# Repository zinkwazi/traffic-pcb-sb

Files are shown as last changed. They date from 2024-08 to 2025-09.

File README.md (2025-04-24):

# Traffic PCB SB
This project is a decorative and interactive display piece that shows the current traffic in the greater Los Angeles area. It sources data from [TomTom's](https://www.tomtom.com) traffic APIs, which supplies real-time traffic data. Each LED corresponds to an OpenLR road segment and data is queried from TomTom every hour. The way data is retrieved is likely to improve in the future. The device uses an ESP32S3 to control LEDs and refreshes the display every 5 minutes, during which LED colors will update if a change in road speed occurs. Please
reference the User Guide below to understand how to configure the device and interpret indicator lights. Enjoy!

# Features
1. Real-time traffic updates of 403 LEDs and nearly 800 data points.
2. Over the air (OTA) updates with daily firmware availability checks.
3. UART configuration menu (115200 baud) stored in non-volatile memory (remembered across reboots).
4. Offline operation with the most recently collected data displayed.

# User Manual
### Quickstart Guide
In order to start using your board, you must first configure it to connect to a wifi network. This is achieved through a 115200 baud UART menu exposed via the USB-C connector. Once connecting your USB-C cable to your computer, a COM device should be discoverable and communication via UART can be opened in the Arduino IDE or another program. The menu should open automatically and prompt you for wifi credentials (note that backspace is not accepted). If it does not open automatically, the menu is accessable by holding the "Toggle" button (until the menu is opened) and pressing the "Restart" button. Once configuration is complete, the device will reset. Then, the device will spend some time loading and collecting road segment data. It will refresh the LEDs once complete, after which pressing the "Toggle" button will change the direction of traffic flow being displayed from the Southeast direction to the Northwest direction. If a firmware update is available, with newer features and bug fixes, the OTA indicator light will strobe green. Pressing the "Update" button will download the update and the light will turn solid green if successful, otherwise it will turn solid
red if unsucessful.

### Board Anatomy


In the lower left corner of the board is the control panel and above that is the direction panel. The three chips located throughout the board are LED matrix drivers which receive commands via I2C from the ESP32S3. The control panel contains the USB-C connector, which communicates with the ESP32S3 via UART at 115200 baud; the 'Update' button, which initiates an over the air update; the 'Restart' button, which reboots the ESP32S3; and status LED indicators. The direction panel contains the 'Toggle' button and LED indicators that show the current traffic direction being displayed — either Southeast or Northwest.

### Understanding Road LEDs
Each road LED on the board corresponds to two OpenLR road segments: one northbound, and one southbound. Some road segments cross the coordinates of multiple LEDs, which are all refreshed with a single API call. Version 2 of the device features configurable LED colors, where the legend of colors is located just below the direction panel. Road segments are classified as fast (always blue or green in version 1) when the segment speed is at least 80% of its normal speed, medium (orange or yellow in version 1) when between 50% and 80%, and slow (red in version 1) when below 50% of its normal speed. Finally, LEDs at intersections of freeways always prioritize showing the segment speed of the freeway oriented most vertically.

### LED Indicator States
The board can be in one of the following states, discussed further below:
- Initialization: The traffic direction LEDs are strobing in a loading circle pattern. The device has just been powered on or rebooted, and is initializing the device. This may take longer than expected if there is trouble connecting to the wifi network.
- Configuration change is requested: The error LED is on and the traffic direction LEDs are flashing.
- An OTA update is available: The OTA LED is strobing green. Pressing the "Update" button will update the firmware to the latest version if connected to wifi.
- An OTA update is in progress: The OTA LED is solid white. After updating, the LED will momentarily turn either green or red to indicate update success or failure.
- A server error has occurred: The error LED is flashing. This indicates that data retrieval has failed, and the device may not be displaying live data anymore.
- A fatal error has occurred: The error LED momentarily turns red, and the device resets. This can happen for a variety of reasons. If this occurs often, an issue can be created in this repository and you will be helped in a timely manner.

### Configuration Changes
The user can change which wifi network the device attempts to connect to through a 115200 baud UART menu exposed via the USB-C connector. This menu is accessed by holding the "Toggle" button (until the menu is opened) and pressing the "Restart" button. The menu is active when the error LED is on and the traffic LEDs are flashing. If you are having trouble accessing the menu, please be sure to hold the "Toggle" button until these indicators are active. The device will request various configuration settings and, unfortunately, you will not be able to see what you type until you press ENTER. Once configuration is complete, the device will reset. A known bug is that the device cannot connect to some networks with particular SSIDs (names); For example, it will not connect to a network named "Jaden's IPhone", however it will connect to "JadenIPhone".

### Versioning
In the 'releases' tab of the repository you can find various firmware binaries that can manually be flashed onto the device in case something goes wrong with OTA updates, or you would prefer a previous device version. Please note that patch versions, v0.0.X, are mandatory and the device will automatically update to the latest known patch version if it is still available on the server. For example, if the latest available version on the server is v0.7.3 and you manually flash v0.7.1 onto the device, the device will automatically update to v0.7.3. However, if you flash v0.6.0, then the device will not update to any v0.6.X or v0.7.X manually.

Hardware versions are denoted: V[hardware_version]_[hardware_revision]. The hardware version and revision of your board is indicated just above the control panel.
Firmware versions are denoted: v[major_version].[minor_version].[patch_version]. Patch updates are mandatory, but major/minor version updates will be indicated as available.

# Contribution Guide

### Flashing Firmware Guide (preliminary)
1. download vscode
2. on the lefthand side, open extensions tab (four boxes button)
3. search for ESP-IDF from espressif and download
4. Open setup wizard (alternatively cmd+shift+p, then ">ESP-IDF: Setup extension")
5. clone repo
6. open esp-firmware folder and use setup wizard again if necessary, use v5.4.x or v5.3.x.
7. wait for download to complete, follow terminal instructions if errors. This is very likely to be a problematic step,
and unfortunately will not allow the next steps to work if it fails. If
there are issues, follow [ESP-IDF Get Started Guide](https://docs.espressif.com/projects/esp-idf/en/stable/esp32/get-started/index.html) instructions. Again,
this is highly likely to be very problematic and will likely require a lot of troubleshooting. Navigating to user/esp/install.sh and user/esp/export.sh and running ./install.sh might fix it. Also, running
"sudo -H ./install.sh" after restarting the terminal on MAC may be helpful. I think that the v5.3.x script requires python < v3.8, however the tool downloads v3.9 automatically? I recommend trying v5.4.x
if this happens, but really this is an issue to ask esp-idf maintainers about how to solve.
9. if everthing is done, go to commands with (cmd+shift+p).
10. Execute ">ESP-IDF: Select Project Configuration" and choose developV2_0 if flashing for hardware version 2.
11. On the bottom blue bar, if "esp32" is shown as the device target, change it to "esp32s3" for hardware version 2. This step is important, as it creates the build directory and sdkconfig file.
12. click on the wrench icon in the bottom blue bar to build the project under the chosen configuration. Alternatively,
use command "ESP-IDF: Build your project". Wait for the build to complete. If there are errors, contact Jaden or fix them.
13. Plug in board to usb port and hold "Update" through a click of "Restart". Continue holding update until a new COM port
is discovered in the device manager. Holding "Update" through a restart boots the ESP32 into USB flashing mode.
11. Click the plug symbol on the blue bar to select the correct COM port, or execute ">ESP-IDF: Select Port" and 
select the correct port for the connected board.
12. Click the star symbol, or execute ">ESP-IDF: Select flash method" and choose UART.
13. Click either the lightning bolt symbol or flame symbol to either flash the device or flash the device and then monitor
the device logs, respectively. Alternatively, use the corresponding commands: "ESP-IDF: Flash your project" and
"ESP-IDF: Build, Flash, and Monitor".
14. Monitor the output, which should display the firmware and hardware version in red at some point. If the hardware version
is not V2_0, then you have flashed V1_0 firmware to the device and need to select the develop_V2_0 configuration with
"ESP-IDF: Select project configuration". If the firmware version is not v0.5.x, then an issue exists, which is likely that
the default build configurations have not made it into the build. Contact Jaden for help.
15. If the device is asking for wifi settings, type them in carefully (you currently cannot use backspace), however don't
worry if the credentials are incorrect as you can change them later. The device will reset.
16. Give the device some time to perform initialization and grab initial data. Watch the logs for any errors, or watch
the error LED, which will blink or be solid red if something went wrong, such as the wifi credentials being incorrect.
17. To change the wifi credentials again, hold "Toggle" through a reset and be very patient because, for some yet unknown
reason, the device has a crazy boot time. You will boot into the wifi configuration menu where you can update the wifi
credentials.
18. Congrats! Things should be working. If not, contact Jaden.

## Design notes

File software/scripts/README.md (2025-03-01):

## generate_led_coordinates.py

**Assists in the generation of C arrays which describe the x, y PCB coordinates
of each LED on a version of the board.**

**Input:** A CSV file containing the CPL data of every designator on the board. This
should include at least the following headers: "Designator", "Mid X", "Mid Y".
The script will ignore all designators not of the form "LEDx", where x is a 
unique integer.

**Example Input:**

```
Designator,Val,Package,Mid X,Mid Y,Rotation,Layer
F1,3A,Fuse_1206_3216Metric,9.271,-182.499,-90,top
F2,3A,Fuse_1206_3216Metric,58,-163.5,180,top
J2,USB C,USB_C_Receptacle_HRO_TYPE-C-31-M-12,4,-177.8,-90,top
LED1,LED_ARGB,LED_RGB_0606,5.0292,-27.0256,0,top
LED2,LED_ARGB,LED_RGB_0606,39.7256,-29.972,0,top
LED6,LED_ARGB,LED_RGB_0606,197.9168,-86.5124,0,top
LED5,LED_ARGB,LED_RGB_0606,201.1172,-88.8492,0,top
LED4,LED_ARGB,LED_RGB_0606,204.8256,-90.4748,0,top
```

**Output:** A text file containing the C array describing the PCB's LED x, y coordinates,
where each index 'i' in the array corresponds to LED 'i'.. A comment is created 
alongside any indices that did not have a corresponding entry in the input file. 
Fractional portions of the input coordinates are rounded to the nearest integer.

**Example Output:**

```
/* A mapping from LED number to corresponding
x, y PCB coordinates. */
static const LEDCoord LEDNumToCoord[] = {
    {0, 0}, // there is no LED with number 0
    {5, -27}, // 1
    {40, -30}, // 2
    {0, 0}, // there is no LED with number 3
    {205, -90}, // 4
    {201, -89}, // 5
};
```

**Example Explanation:** Input designators F1, F2, and J2 are ignored and do
not affect the output. Similarly, the order of designators "LEDx" is ignored.
Index 2 of the output contains the "Mid X" and "Mid Y" respectively, rounded
to the nearest integer. There is no "LED3" designator, so index 3 of the output
is set to {0, 0} and a comment is created documenting absence.

**Usage:** 
```
python3 generate_led_coordinates.py inputCPL.csv [output.txt]
```

If no output file is provided, the script will present the generated struct
to stdout.

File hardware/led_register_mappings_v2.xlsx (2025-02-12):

MATRIX4 |  | 1 | 2 | 3 | 4 | 5 | 6 | 7 | 8 | 9 | MATRIX4 |  | 1 | 2 | 3 | 4 | 5 | 6 | 7 | 8 | 9
 |  | COL8 | COL7 | COL6 | COL5 | COL4 | COL0 | COL1 | COL2 | COL3 |  |  | COL0 | COL1 | COL2 | COL3 | COL4 | COL5 | COL6 | COL7 | COL8
39 | ROW1 | 0x62 | 0x6B | 0x74 | 0x7D | 0x86 | 0x8F | 0x98 | 0xA1 | 0xAA | 39 | ROW1 | 0x8F | 0x98 | 0xA1 | 0xAA | 0x86 | 0x7D | 0x74 | 0x6B | 0x62
38 | ROW2 | 0x61 | 0x6A | 0x73 | 0x7C | 0x85 | 0x8E | 0x97 | 0xA0 | 0xA9 | 38 | ROW2 | 0x8E | 0x97 | 0xA0 | 0xA9 | 0x85 | 0x7C | 0x73 | 0x6A | 0x61
37 | ROW0 | 0x60 | 0x69 | 0x72 | 0x7B | 0x84 | 0x8D | 0x96 | 0x9F | 0xA8 | 37 | ROW0 | 0x8D | 0x96 | 0x9F | 0xA8 | 0x84 | 0x7B | 0x72 | 0x69 | 0x60
36 | ROW4 | 0x5F | 0x68 | 0x71 | 0x7A | 0x83 | 0x8C | 0x95 | 0x9E | 0xA7 | 36 | ROW4 | 0x8C | 0x95 | 0x9E | 0xA7 | 0x83 | 0x7A | 0x71 | 0x68 | 0x5F
35 | ROW5 | 0x5E | 0x67 | 0x70 | 0x79 | 0x82 | 0x8B | 0x94 | 0x9D | 0xA6 | 35 | ROW5 | 0x8B | 0x94 | 0x9D | 0xA6 | 0x82 | 0x79 | 0x70 | 0x67 | 0x5E
34 | ROW3 | 0x5D | 0x66 | 0x6F | 0x78 | 0x81 | 0x8A | 0x93 | 0x9C | 0xA5 | 34 | ROW3 | 0x8A | 0x93 | 0x9C | 0xA5 | 0x81 | 0x78 | 0x6F | 0x66 | 0x5D
33 | ROW8 | 0x5C | 0x65 | 0x6E | 0x77 | 0x80 | 0x89 | 0x92 | 0x9B | 0xA4 | 33 | ROW8 | 0x89 | 0x92 | 0x9B | 0xA4 | 0x80 | 0x77 | 0x6E | 0x65 | 0x5C
32 | ROW7 | 0x5B | 0x64 | 0x6D | 0x76 | 0x7F | 0x88 | 0x91 | 0x9A | 0xA3 | 32 | ROW7 | 0x88 | 0x91 | 0x9A | 0xA3 | 0x7F | 0x76 | 0x6D | 0x64 | 0x5B
31 | ROW6 | 0x5A | 0x63 | 0x6C | 0x75 | 0x7E | 0x87 | 0x90 | 0x99 | 0xA2 | 31 | ROW6 | 0x87 | 0x90 | 0x99 | 0xA2 | 0x7E | 0x75 | 0x6C | 0x63 | 0x5A
30 | ROW11 | 0x1D | 0x3B | 0x59 | 0x77 | 0x95 | 0xB3 | 0x1D | 0x3B | 0x59 | 30 | ROW11 | 0xB3 | 0x1D | 0x3B | 0x59 | 0x95 | 0x77 | 0x59 | 0x3B | 0x1D
29 | ROW10 | 0x1C | 0x3A | 0x58 | 0x76 | 0x94 | 0xB2 | 0x1C | 0x3A | 0x58 | 29 | ROW10 | 0xB2 | 0x1C | 0x3A | 0x58 | 0x94 | 0x76 | 0x58 | 0x3A | 0x1C
28 | ROW9 | 0x1B | 0x39 | 0x57 | 0x75 | 0x93 | 0xB1 | 0x1B | 0x39 | 0x57 | 28 | ROW9 | 0xB1 | 0x1B | 0x39 | 0x57 | 0x93 | 0x75 | 0x57 | 0x39 | 0x1B
27 | ROW14 | 0x1A | 0x38 | 0x56 | 0x74 | 0x92 | 0xB0 | 0x1A | 0x38 | 0x56 | 27 | ROW14 | 0xB0 | 0x1A | 0x38 | 0x56 | 0x92 | 0x74 | 0x56 | 0x38 | 0x1A
26 | ROW13 | 0x19 | 0x37 | 0x55 | 0x73 | 0x91 | 0xAF | 0x19 | 0x37 | 0x55 | 26 | ROW13 | 0xAF | 0x19 | 0x37 | 0x55 | 0x91 | 0x73 | 0x55 | 0x37 | 0x19
25 | ROW12 | 0x18 | 0x36 | 0x54 | 0x72 | 0x90 | 0xAE | 0x18 | 0x36 | 0x54 | 25 | ROW12 | 0xAE | 0x18 | 0x36 | 0x54 | 0x90 | 0x72 | 0x54 | 0x36 | 0x18
24 | ROW17 | 0x17 | 0x35 | 0x53 | 0x71 | 0x8F | 0xAD | 0x17 | 0x35 | 0x53 | 24 | ROW17 | 0xAD | 0x17 | 0x35 | 0x53 | 0x8F | 0x71 | 0x53 | 0x35 | 0x17
23 | ROW16 | 0x16 | 0x34 | 0x52 | 0x70 | 0x8E | 0xAC | 0x16 | 0x34 | 0x52 | 23 | ROW16 | 0xAC | 0x16 | 0x34 | 0x52 | 0x8E | 0x70 | 0x52 | 0x34 | 0x16
22 | ROW15 | 0x15 | 0x33 | 0x51 | 0x6F | 0x8D | 0xAB | 0x15 | 0x33 | 0x51 | 22 | ROW15 | 0xAB | 0x15 | 0x33 | 0x51 | 0x8D | 0x6F | 0x51 | 0x33 | 0x15
21 | ROW19 | 0x14 | 0x32 | 0x50 | 0x6E | 0x8C | 0xAA | 0x14 | 0x32 | 0x50 | 21 | ROW19 | 0xAA | 0x14 | 0x32 | 0x50 | 0x8C | 0x6E | 0x50 | 0x32 | 0x14
20 | ROW20 | 0x13 | 0x31 | 0x4F | 0x6D | 0x8B | 0xA9 | 0x13 | 0x31 | 0x4F | 20 | ROW20 | 0xA9 | 0x13 | 0x31 | 0x4F | 0x8B | 0x6D | 0x4F | 0x31 | 0x13
19 | ROW18 | 0x12 | 0x30 | 0x4E | 0x6C | 0x8A | 0xA8 | 0x12 | 0x30 | 0x4E | 19 | ROW18 | 0xA8 | 0x12 | 0x30 | 0x4E | 0x8A | 0x6C | 0x4E | 0x30 | 0x12
18 | ROW26 | 0x11 | 0x2F | 0x4D | 0x6B | 0x89 | 0xA7 | 0x11 | 0x2F | 0x4D | 18 | ROW26 | 0xA7 | 0x11 | 0x2F | 0x4D | 0x89 | 0x6B | 0x4D | 0x2F | 0x11
17 | ROW25 | 0x10 | 0x2E | 0x4C | 0x6A | 0x88 | 0xA6 | 0x10 | 0x2E | 0x4C | 17 | ROW25 | 0xA6 | 0x10 | 0x2E | 0x4C | 0x88 | 0x6A | 0x4C | 0x2E | 0x10
16 | ROW24 | 0x0F | 0x2D | 0x4B | 0x69 | 0x87 | 0xA5 | 0x0F | 0x2D | 0x4B | 16 | ROW24 | 0xA5 | 0x0F | 0x2D | 0x4B | 0x87 | 0x69 | 0x4B | 0x2D | 0x0F
15 | ROW23 | 0x0E | 0x2C | 0x4A | 0x68 | 0x86 | 0xA4 | 0x0E | 0x2C | 0x4A | 15 | ROW23 | 0xA4 | 0x0E | 0x2C | 0x4A | 0x86 | 0x68 | 0x4A | 0x2C | 0x0E
14 | ROW22 | 0x0D | 0x2B | 0x49 | 0x67 | 0x85 | 0xA3 | 0x0D | 0x2B | 0x49 | 14 | ROW22 | 0xA3 | 0x0D | 0x2B | 0x49 | 0x85 | 0x67 | 0x49 | 0x2B | 0x0D
13 | ROW21 | 0x0C | 0x2A | 0x48 | 0x66 | 0x84 | 0xA2 | 0x0C | 0x2A | 0x48 | 13 | ROW21 | 0xA2 | 0x0C | 0x2A | 0x48 | 0x84 | 0x66 | 0x48 | 0x2A | 0x0C
12 | ROW35 | 0x0B | 0x29 | 0x47 | 0x65 | 0x83 | 0xA1 | 0x0B | 0x29 | 0x47 | 12 | ROW35 | 0xA1 | 0x0B | 0x29 | 0x47 | 0x83 | 0x65 | 0x47 | 0x29 | 0x0B
11 | ROW34 | 0x0A | 0x28 | 0x46 | 0x64 | 0x82 | 0xA0 | 0x0A | 0x28 | 0x46 | 11 | ROW34 | 0xA0 | 0x0A | 0x28 | 0x46 | 0x82 | 0x64 | 0x46 | 0x28 | 0x0A
10 | ROW33 | 0x09 | 0x27 | 0x45 | 0x63 | 0x81 | 0x9F | 0x09 | 0x27 | 0x45 | 10 | ROW33 | 0x9F | 0x09 | 0x27 | 0x45 | 0x81 | 0x63 | 0x45 | 0x27 | 0x09
9 | ROW32 | 0x08 | 0x26 | 0x44 | 0x62 | 0x80 | 0x9E | 0x08 | 0x26 | 0x44 | 9 | ROW32 | 0x9E | 0x08 | 0x26 | 0x44 | 0x80 | 0x62 | 0x44 | 0x26 | 0x08
8 | ROW31 | 0x07 | 0x25 | 0x43 | 0x61 | 0x7F | 0x9D | 0x07 | 0x25 | 0x43 | 8 | ROW31 | 0x9D | 0x07 | 0x25 | 0x43 | 0x7F | 0x61 | 0x43 | 0x25 | 0x07
7 | ROW30 | 0x06 | 0x24 | 0x42 | 0x60 | 0x7E | 0x9C | 0x06 | 0x24 | 0x42 | 7 | ROW30 | 0x9C | 0x06 | 0x24 | 0x42 | 0x7E | 0x60 | 0x42 | 0x24 | 0x06
6 | ROW29 | 0x05 | 0x23 | 0x41 | 0x5F | 0x7D | 0x9B | 0x05 | 0x23 | 0x41 | 6 | ROW29 | 0x9B | 0x05 | 0x23 | 0x41 | 0x7D | 0x5F | 0x41 | 0x23 | 0x05
5 | ROW28 | 0x04 | 0x22 | 0x40 | 0x5E | 0x7C | 0x9A | 0x04 | 0x22 | 0x40 | 5 | ROW28 | 0x9A | 0x04 | 0x22 | 0x40 | 0x7C | 0x5E | 0x40 | 0x22 | 0x04
4 | ROW27 | 0x03 | 0x21 | 0x3F | 0x5D | 0x7B | 0x99 | 0x03 | 0x21 | 0x3F | 4 | ROW27 | 0x99 | 0x03 | 0x21 | 0x3F | 0x7B | 0x5D | 0x3F | 0x21 | 0x03
3 | ROW38 | 0x02 | 0x20 | 0x3E | 0x5C | 0x7A | 0x98 | 0x02 | 0x20 | 0x3E | 3 | ROW38 | 0x98 | 0x02 | 0x20 | 0x3E | 0x7A | 0x5C | 0x3E | 0x20 | 0x02
2 | ROW37 | 0x01 | 0x1F | 0x3D | 0x5B | 0x79 | 0x97 | 0x01 | 0x1F | 0x3D | 2 | ROW37 | 0x97 | 0x01 | 0x1F | 0x3D | 0x79 | 0x5B | 0x3D | 0x1F | 0x01
1 | ROW36 | 0x00 | 0x1E | 0x3C | 0x5A | 0x78 | 0x96 | 0x00 | 0x1E | 0x3C | 1 | ROW36 | 0x96 | 0x00 | 0x1E | 0x3C | 0x78 | 0x5A | 0x3C | 0x1E | 0x00
MATRIX4 |  | 1 | 2 | 3 | 4 | 5 | 6 | 7 | 8 | 9 | MATRIX 1 |  | 1 |  | 2 |  | 3 |  | 4 |  | 5 |  | 6 |  | 7 |  | 8 |  | 9
 |  | COL0 | COL1 | COL2 | COL3 | COL4 | COL5 | COL6 | COL7 | COL8 |  | LED NUM | COL0 |  | COL1 |  | COL2 |  | COL3 |  | COL4 |  | COL5 |  | COL6 |  | COL7 |  | COL8
37 | ROW0 | 0x8D | 0x96 | 0x9F | 0xA8 | 0x84 | 0x7B | 0x72 | 0x69 | 0x60 | 37 | ROW0 | 0x8D | 1 | 0x96 | 2 | 0x9F | 3 | 0xA8 | 4 | 0x84 | 5 | 0x7B | 6 | 0x72 | 7 | 0x69 | 8 | 0x60 | 9
39 | ROW1 | 0x8F | 0x98 | 0xA1 | 0xAA | 0x86 | 0x7D | 0x74 | 0x6B | 0x62 | 39 | ROW1 | 0x8F |  | 0x98 |  | 0xA1 |  | 0xAA |  | 0x86 |  | 0x7D |  | 0x74 |  | 0x6B |  | 0x62
38 | ROW2 | 0x8E | 0x97 | 0xA0 | 0xA9 | 0x85 | 0x7C | 0x73 | 0x6A | 0x61 | 38 | ROW2 | 0x8E |  | 0x97 |  | 0xA0 |  | 0xA9 |  | 0x85 |  | 0x7C |  | 0x73 |  | 0x6A |  | 0x61
34 | ROW3 | 0x8A | 0x93 | 0x9C | 0xA5 | 0x81 | 0x78 | 0x6F | 0x66 | 0x5D | 34 | ROW3 | 0x8A | 10 | 0x93 | 11 | 0x9C | 12 | 0xA5 | 13 | 0x81 | 14 | 0x78 | 15 | 0x6F | 16 | 0x66 | 17 | 0x5D | 18
36 | ROW4 | 0x8C | 0x95 | 0x9E | 0xA7 | 0x83 | 0x7A | 0x71 | 0x68 | 0x5F | 36 | ROW4 | 0x8C |  | 0x95 |  | 0x9E |  | 0xA7 |  | 0x83 |  | 0x7A |  | 0x71 |  | 0x68 |  | 0x5F
35 | ROW5 | 0x8B | 0x94 | 0x9D | 0xA6 | 0x82 | 0x79 | 0x70 | 0x67 | 0x5E | 35 | ROW5 | 0x8B |  | 0x94 |  | 0x9D |  | 0xA6 |  | 0x82 |  | 0x79 |  | 0x70 |  | 0x67 |  | 0x5E
31 | ROW6 | 0x87 | 0x90 | 0x99 | 0xA2 | 0x7E | 0x75 | 0x6C | 0x63 | 0x5A | 31 | ROW6 | 0x87 | 19 | 0x90 | 20 | 0x99 | 21 | 0xA2 | 22 | 0x7E | 23 | 0x75 | 24 | 0x6C | 25 | 0x63 | 26 | 0x5A | 27
32 | ROW7 | 0x88 | 0x91 | 0x9A | 0xA3 | 0x7F | 0x76 | 0x6D | 0x64 | 0x5B | 32 | ROW7 | 0x88 |  | 0x91 |  | 0x9A |  | 0xA3 |  | 0x7F |  | 0x76 |  | 0x6D |  | 0x64 |  | 0x5B
33 | ROW8 | 0x89 | 0x92 | 0x9B | 0xA4 | 0x80 | 0x77 | 0x6E | 0x65 | 0x5C | 33 | ROW8 | 0x89 |  | 0x92 |  | 0x9B |  | 0xA4 |  | 0x80 |  | 0x77 |  | 0x6E |  | 0x65 |  | 0x5C
28 | ROW9 | 0xB1 | 0x1B | 0x39 | 0x57 | 0x93 | 0x75 | 0x57 | 0x39 | 0x1B | 28 | ROW9 | 0xB1 | 28 | 0x1B | 29 | 0x39 | 30 | 0x57 | 31 | 0x93 | 32 | 0x75 | 33 | 0x57 | 34 | 0x39 | 35 | 0x1B | 36
29 | ROW10 | 0xB2 | 0x1C | 0x3A | 0x58 | 0x94 | 0x76 | 0x58 | 0x3A | 0x1C | 29 | ROW10 | 0xB2 |  | 0x1C |  | 0x3A |  | 0x58 |  | 0x94 |  | 0x76 |  | 0x58 |  | 0x3A |  | 0x1C
30 | ROW11 | 0xB3 | 0x1D | 0x3B | 0x59 | 0x95 | 0x77 | 0x59 | 0x3B | 0x1D | 30 | ROW11 | 0xB3 |  | 0x1D |  | 0x3B |  | 0x59 |  | 0x95 |  | 0x77 |  | 0x59 |  | 0x3B |  | 0x1D
25 | ROW12 | 0xAE | 0x18 | 0x36 | 0x54 | 0x90 | 0x72 | 0x54 | 0x36 | 0x18 | 25 | ROW12 | 0xAE | 37 | 0x18 | 38 | 0x36 | 39 | 0x54 | 40 | 0x90 | 41 | 0x72 | 42 | 0x54 | 43 | 0x36 | 44 | 0x18 | 45
26 | ROW13 | 0xAF | 0x19 | 0x37 | 0x55 | 0x91 | 0x73 | 0x55 | 0x37 | 0x19 | 26 | ROW13 | 0xAF |  | 0x19 |  | 0x37 |  | 0x55 |  | 0x91 |  | 0x73 |  | 0x55 |  | 0x37 |  | 0x19
27 | ROW14 | 0xB0 | 0x1A | 0x38 | 0x56 | 0x92 | 0x74 | 0x56 | 0x38 | 0x1A | 27 | ROW14 | 0xB0 |  | 0x1A |  | 0x38 |  | 0x56 |  | 0x92 |  | 0x74 |  | 0x56 |  | 0x38 |  | 0x1A
22 | ROW15 | 0xAB | 0x15 | 0x33 | 0x51 | 0x8D | 0x6F | 0x51 | 0x33 | 0x15 | 22 | ROW15 | 0xAB | 55 | 0x15 | 56 | 0x33 | 57 | 0x51 | 58 | 0x8D | 59 | 0x6F | 60 | 0x51 | 61 | 0x33 | 62 | 0x15 | 63
23 | ROW16 | 0xAC | 0x16 | 0x34 | 0x52 | 0x8E | 0x70 | 0x52 | 0x34 | 0x16 | 23 | ROW16 | 0xAC |  | 0x16 |  | 0x34 |  | 0x52 |  | 0x8E |  | 0x70 |  | 0x52 |  | 0x34 |  | 0x16
24 | ROW17 | 0xAD | 0x17 | 0x35 | 0x53 | 0x8F | 0x71 | 0x53 | 0x35 | 0x17 | 24 | ROW17 | 0xAD |  | 0x17 |  | 0x35 |  | 0x53 |  | 0x8F |  | 0x71 |  | 0x53 |  | 0x35 |  | 0x17
19 | ROW18 | 0xA8 | 0x12 | 0x30 | 0x4E | 0x8A | 0x6C | 0x4E | 0x30 | 0x12 | 19 | ROW18 | 0xA8 | 73 | 0x12 | 74 | 0x30 | 75 | 0x4E | 76 | 0x8A | 77 | 0x6C | 78 | 0x4E | 79 | 0x30 | 80 | 0x12 | 81
21 | ROW19 | 0xAA | 0x14 | 0x32 | 0x50 | 0x8C | 0x6E | 0x50 | 0x32 | 0x14 | 21 | ROW19 | 0xAA |  | 0x14 |  | 0x32 |  | 0x50 |  | 0x8C |  | 0x6E |  | 0x50 |  | 0x32 |  | 0x14
20 | ROW20 | 0xA9 | 0x13 | 0x31 | 0x4F | 0x8B | 0x6D | 0x4F | 0x31 | 0x13 | 20 | ROW20 | 0xA9 |  | 0x13 |  | 0x31 |  | 0x4F |  | 0x8B |  | 0x6D |  | 0x4F |  | 0x31 |  | 0x13
13 | ROW21 | 0xA2 | 0x0C | 0x2A | 0x48 | 0x84 | 0x66 | 0x48 | 0x2A | 0x0C | 13 | ROW21 | 0xA2 | 82 | 0x0C | 83 | 0x2A | 84 | 0x48 | 85 | 0x84 | 86 | 0x66 | 87 | 0x48 | 88 | 0x2A | 89 | 0x0C | 90
14 | ROW22 | 0xA3 | 0x0D | 0x2B | 0x49 | 0x85 | 0x67 | 0x49 | 0x2B | 0x0D | 14 | ROW22 | 0xA3 |  | 0x0D |  | 0x2B |  | 0x49 |  | 0x85 |  | 0x67 |  | 0x49 |  | 0x2B |  | 0x0D
15 | ROW23 | 0xA4 | 0x0E | 0x2C | 0x4A | 0x86 | 0x68 | 0x4A | 0x2C | 0x0E | 15 | ROW23 | 0xA4 |  | 0x0E |  | 0x2C |  | 0x4A |  | 0x86 |  | 0x68 |  | 0x4A |  | 0x2C |  | 0x0E
16 | ROW24 | 0xA5 | 0x0F | 0x2D | 0x4B | 0x87 | 0x69 | 0x4B | 0x2D | 0x0F | 16 | ROW24 | 0xA5 | 100 | 0x0F | 101 | 0x2D | 102 | 0x4B | 103 | 0x87 | 104 | 0x69 | 105 | 0x4B | 106 | 0x2D | 107 | 0x0F | 108
17 | ROW25 | 0xA6 | 0x10 | 0x2E | 0x4C | 0x88 | 0x6A | 0x4C | 0x2E | 0x10 | 17 | ROW25 | 0xA6 |  | 0x10 |  | 0x2E |  | 0x4C |  | 0x88 |  | 0x6A |  | 0x4C |  | 0x2E |  | 0x10
18 | ROW26 | 0xA7 | 0x11 | 0x2F | 0x4D | 0x89 | 0x6B | 0x4D | 0x2F | 0x11 | 18 | ROW26 | 0xA7 |  | 0x11 |  | 0x2F |  | 0x4D |  | 0x89 |  | 0x6B |  | 0x4D |  | 0x2F |  | 0x11
4 | ROW27 | 0x99 | 0x03 | 0x21 | 0x3F | 0x7B | 0x5D | 0x3F | 0x21 | 0x03 | 4 | ROW27 | 0x99 | 109 | 0x03 | 110 | 0x21 | 111 | 0x3F | 112 | 0x7B | 113 | 0x5D | 114 | 0x3F | 115 | 0x21 | 116 | 0x03 | 414
5 | ROW28 | 0x9A | 0x04 | 0x22 | 0x40 | 0x7C | 0x5E | 0x40 | 0x22 | 0x04 | 5 | ROW28 | 0x9A |  | 0x04 |  | 0x22 |  | 0x40 |  | 0x7C |  | 0x5E |  | 0x40 |  | 0x22 |  | 0x04
6 | ROW29 | 0x9B | 0x05 | 0x23 | 0x41 | 0x7D | 0x5F | 0x41 | 0x23 | 0x05 | 6 | ROW29 | 0x9B |  | 0x05 |  | 0x23 |  | 0x41 |  | 0x7D |  | 0x5F |  | 0x41 |  | 0x23 |  | 0x05
7 | ROW30 | 0x9C | 0x06 | 0x24 | 0x42 | 0x7E | 0x60 | 0x42 | 0x24 | 0x06 | 7 | ROW30 | 0x9C | 145 | 0x06 | 146 | 0x24 | 147 | 0x42 | 148 | 0x7E | 149 | 0x60 | 150 | 0x42 | 151 | 0x24 | 152 | 0x06 | 153
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

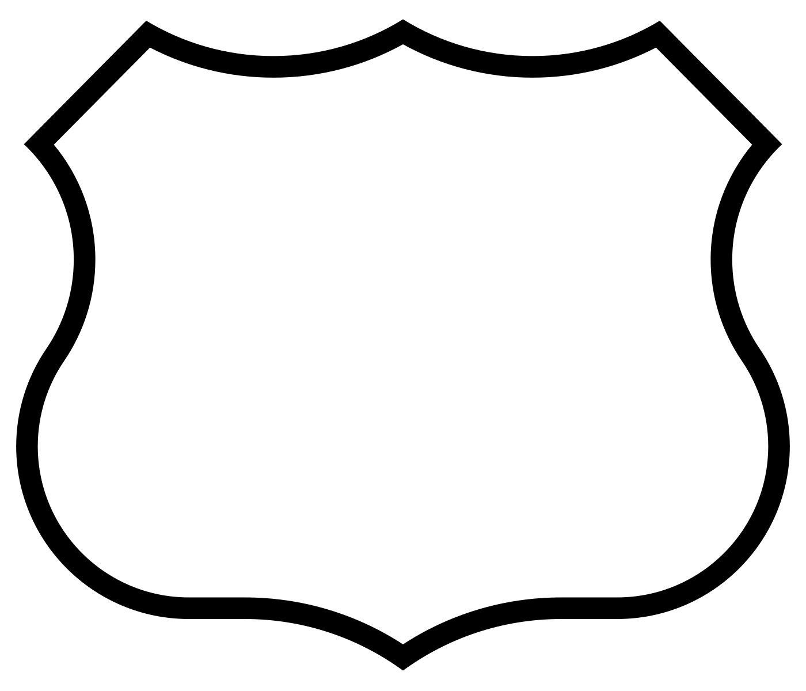
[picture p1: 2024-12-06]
hardware/kicad/graphics/highway_symbol.jpg

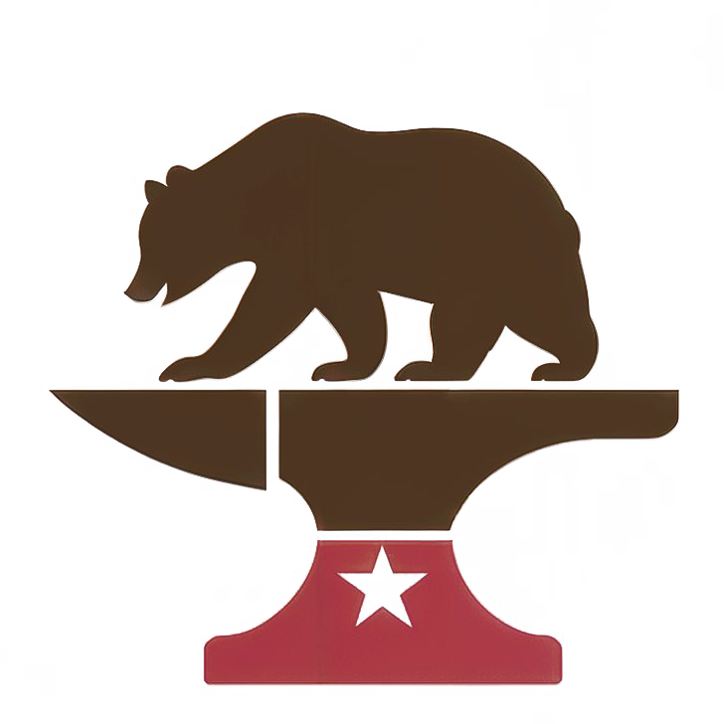
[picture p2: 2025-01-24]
hardware/kicad/graphics/bearanvil.png

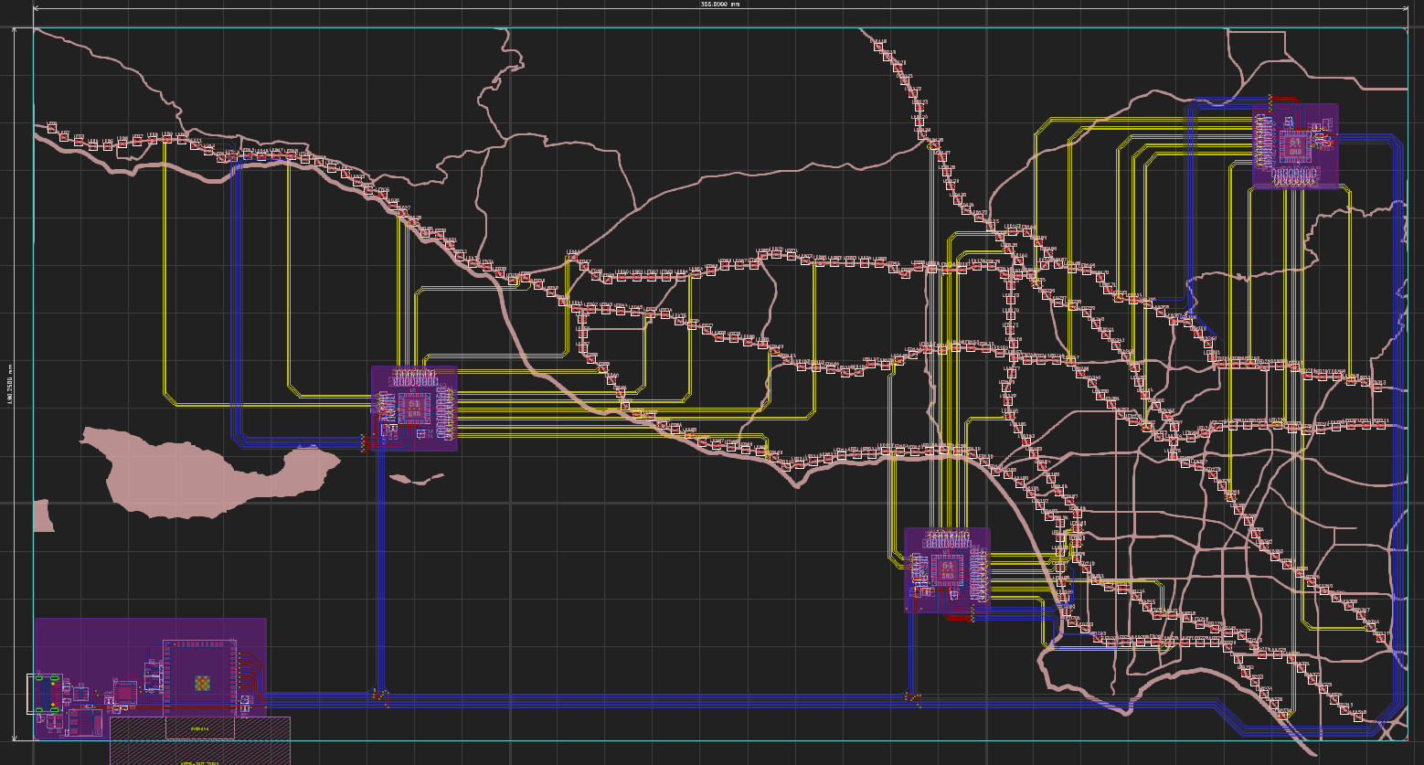
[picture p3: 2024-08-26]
images/traffic-sb-traces.png

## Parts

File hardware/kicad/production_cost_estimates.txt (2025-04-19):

JLCPCB:

QTY 5:
20 matrices @ 2.23 = $44.60 plus some assembly cost
PCB + Assembly, roughly $289.06
Shipping, roughly $51.87
Total Before Tax: ~$340.92
Cost Per Board: ~$68.18

QTY 10: 
40 led matrices @ 2.1525 = $86.10 plus some assembly cost
$0.576 for resistor that is not in library
PCB + Assembly, roughly $400
Shipping, roughly $83
Total Before Tax: ~$570
Cost Per Board: ~$57

QTY 20:
80 led matrices @ 2.1525 = $172.20 plus some assembly cost
$0.80 for a resistor that is not in library
PCB + Assembly, roughly $619
Shipping, roughly $139.67
Total Before Tax: ~$930
Cost Per Board: ~$46.50

QTY 30:
120 led matrices @ 1.9845 = $238.14 plus some assembly cost
Few extra dollars for missing components (not counted)
PCB + Assembly, roughly $809.35
Shipping, roughly $193.57
Total Before Tax: ~$1,250
Cost Per Board: ~$41.67

QTY 50:
200 led matrices @ 1.9845 = $396.90 plus some assembly cost
Few extra dollars for missing components (not counted)
PCB + Assembly, roughly $1,215
Shipping, roughly $315
Total Before Tax: ~$1,927
Cost Per Board: ~$38.54

PCBWAY: Customs duties/VAT not included

QTY 10:
PCB Cost: $249.87
Assembly Service Cost: $471.90
Shipping: $45
Discount: $-30
Total: $737.32

QTY 20:
PCB Cost: $342.13
Assembly Service Cost: $471.90
Shipping: $78.83
Discount: $-30
Total: $862.86

QTY 30:
PCB Cost: $446.07
Assembly Service Cost: $471.90
Shipping: 111.89
Discount: $-30
Total: $999.86

QTY 40:
PCB Cost: $551.89
Assembly Service Cost: $471.90
Shipping: $141.04
Discount: $-30
Total: $1,134.83

QTY 50:
PCB Cost: $655.86
Assembly Service Cost: $471.90
Shipping: $172.77
Discount: $-30
Total: $1,270.53

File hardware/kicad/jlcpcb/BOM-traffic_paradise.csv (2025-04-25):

BOM: traffic-pcb-sb
Assembly Part Number/Revision: V2_1
Customer/Company Name: Jaden Baptista / Outside Open
Item # | Quantity per board | Manufacturer Part # | Do Not Install | Reference designators | Vendor (optional) | Vendor Part Number (optional) | Value (optional) | Size / Footprint (optional) | Part description/ specs (optional, but recommended) | Manfacturer (optional)
1 | 1 | GL5516(5-10) | DNI | R108 | LCSC | C10077 | Photoresistor | Photoresistor | 5k?~10k? 540nm 0.2M? Plugin,P=3.4mm Photoresistors ROHS | JCHL(Shenzhen Jing Chuang He Li Tech)
2 | 102 | RC0402JR-0720RL | DNI | R100,R101,R103,R104,R110,R111,R113,R114,R117,R118,R12,R120,R121,R123,R124,R126,R127,R129,R13,R130,R132,R133,R135,R136,R145,R146,R15,R151,R152,R154,R155,R157,R158,R16,R160,R161,R163,R164,R166,R167,R169,R170,R172,R173,R175,R176,R178,R179,R181,R182,R184,R185,R187,R188,R22,R23,R25,R26,R29,R30,R32,R33,R35,R36,R38,R39,R41,R42,R44,R45,R47,R48,R50,R51,R53,R54,R56,R57,R59,R60,R66,R67,R69,R70,R73,R74,R76,R77,R79,R80,R82,R83,R85,R86,R88,R89,R91,R92,R94,R95,R97,R98 | LCSC | C137901 | 20 | R_0402_1005Metric | 62.5mW Thick Film Resistors 50V ±100ppm/? ±5% 20? 0402 Chip Resistor - Surface Mount ROHS | YAGEO
3 | 2 | CL05A106MQ5NUNC | DNI | C1,C2 | LCSC | C15525 | 10uF | C_0402_1005Metric | 6.3V 10uF X5R ±20% 0402 Multilayer Ceramic Capacitors MLCC - SMD/SMT ROHS | Samsung Electro-Mechanics
4 | 1 | TYPE-C-31-M-12 | DNI | J2 | LCSC | C165948 | USB C | USB_C_Receptacle_HRO_TYPE-C-31-M-12 | 5A 1 16P Female Type-C SMD USB Connectors ROHS | Korean Hroparts Elec
5 | 1 | 0402WGF0000TCE | DNI | R2 | LCSC | C17168 | 0R | R_0402_1005Metric | 1/16W Thick Film Resistors 50V ±800ppm/? ±1% 0? 0402 Chip Resistor - Surface Mount ROHS | UNI-ROYAL(Uniroyal Elec)
6 | 2 | 1206L200/13.2NR | DNI | F1,F2 | LCSC | C19078717 | 3A | Fuse_1206_3216Metric | 13.2V 2A 100A 3.5A 1206 Resettable Fuses ROHS | LUTE
7 | 1 | 0603WAF1501T5E | DNI | R4 | LCSC | C22843 | 1.5k | R_0603_1608Metric | 0.1W Thick Film Resistors 75V ±100ppm/? ±1% 1.5k? 0603 Chip Resistor - Surface Mount ROHS | UNI-ROYAL(Uniroyal Elec)
8 | 1 | 0603WAF9091T5E | DNI | R1 | LCSC | C23125 | 8.5k | R_0603_1608Metric | 0.1W Thick Film Resistors 75V ±100ppm/? ±1% 9.09k? 0603 Chip Resistor - Surface Mount ROHS | UNI-ROYAL(Uniroyal Elec)
9 | 3 | 0402WGF1002TCE | DNI | R138,R140,R65 | LCSC | C25744 | 10k | R_0402_1005Metric | 1/16W Thick Film Resistors 50V ±100ppm/? ±1% 10k? 0402 Chip Resistor - Surface Mount ROHS | UNI-ROYAL(Uniroyal Elec)
10 | 4 | 0603WAF1002T5E | DNI | R115,R149,R27,R71 | LCSC | C25804 | 10k | R_0603_1608Metric | 0.1W Thick Film Resistors 75V ±100ppm/? ±1% 10k? 0603 Chip Resistor - Surface Mount ROHS | UNI-ROYAL(Uniroyal Elec)
11 | 8 | 0402WGF4701TCE | DNI | R106,R107,R147,R148,R18,R19,R62,R63 | LCSC | C25900 | 4.7k | R_0402_1005Metric | 1/16W Thick Film Resistors 50V ±100ppm/? ±1% 4.7k? 0402 Chip Resistor - Surface Mount ROHS | UNI-ROYAL(Uniroyal Elec)
12 | 2 | 0402WGF5101TCE | DNI | R5,R6 | LCSC | C25905 | 5.1k | R_0402_1005Metric | 1/16W Thick Film Resistors 50V ±100ppm/? ±1% 5.1k? 0402 Chip Resistor - Surface Mount ROHS | UNI-ROYAL(Uniroyal Elec)
13 | 1 | ESP32-S3-WROOM-1-N8 | DNI | U13 | LCSC | C2913198 | ESP32-S3-WROOM-1-N8 | ESP32-S3-WROOM-1-N8 | ESP32-S3 Chip 2.4GHz SMD,18x25.5mm WiFi Modules ROHS | Espressif Systems
14 | 1 | FRC0603F1472TS | DNI | R3 | LCSC | C2933148 | 14.5k | R_0603_1608Metric | 0.1W Thick Film Resistors 75V ±100ppm/? ±1% 14.7k? 0603 Chip Resistor - Surface Mount ROHS | FOJAN
15 | 4 | IS31FL3741A-QFLS4-TR | DNI | U12,U5,U6,U7 | LCSC | C2940604 | IS31FL3741A | QFN40P700X700X80-61N | 900Hz~29kHz QFN-60-EP(7x7) LED Drivers ROHS | ISSI(Integrated Silicon Solution)
16 | 2 | S-LMBR340FT1G | DNI | D1,D4 | LCSC | C2972823 | RBR3MM40ATR | DIO_RB051MM_ROM | 40V Independent Type 3A 500mV@3A SOD-123FL Schottky Diodes ROHS | LRC
17 | 1 | AR03BTC2501 | DNI | R7 | LCSC | C304065 | 2.5k | R_0603_1608Metric | 1/16W ±25ppm/? ±0.1% 2.5k? 0603 Chip Resistor - Surface Mount ROHS | Viking Tech
18 | 12 | CL05B104KB54PNC | DNI | C12,C14,C16,C18,C20,C22,C24,C27,C28,C31,C5,C9 | LCSC | C307331 | 0.1uF | C_0402_1005Metric | 50V 100nF X7R ±10% 0402 Multilayer Ceramic Capacitors MLCC - SMD/SMT ROHS | Samsung Electro-Mechanics
19 | 3 | TS-1187A-B-A-B | DNI | SW1,SW2,SW3 | LCSC | C318884 | SW_Push | SW_SPST_SKQG_WithoutStem | None Without bracket 50mA 5.1mm 100000 Times 160gf 12V 5.1mm 1.5mm Round Button Standing paste SPST SMD Tactile Switches ROHS | XKB Connection
20 | 51 | RMC0402511%N | DNI | R102,R105,R109,R11,R112,R116,R119,R122,R125,R128,R131,R134,R14,R150,R153,R156,R159,R162,R165,R168,R17,R171,R174,R177,R180,R183,R186,R24,R28,R31,R34,R37,R40,R43,R46,R49,R52,R55,R58,R61,R68,R72,R75,R78,R81,R84,R87,R90,R93,R96,R99 | LCSC | C325571 | 51 | R_0402_1005Metric | 1/16W ±1% 51? 0402 Chip Resistor - Surface Mount ROHS | TyoHM
21 | 2 | KT-0805W | DNI | D2,D3 | LCSC | C34499 | LED | LED_0805_2012Metric | 25mA Yellow lens 350mcd -30?~+85? Independent Diode Positive Stick White 120° 80mW 2.6V~3.2V 0805 LED Indication - Discrete ROHS | Hubei KENTO Elec
22 | 4 | 0402WGF2001TCE | DNI | R139,R20,R21,R64 | LCSC | C4109 | 2k | R_0402_1005Metric | 1/16W Thick Film Resistors 50V ±100ppm/? ±1% 2k? 0402 Chip Resistor - Surface Mount ROHS | UNI-ROYAL(Uniroyal Elec)
23 | 9 | CL05A105KA5NQNC | DNI | C11,C13,C15,C17,C19,C21,C25,C26,C29 | LCSC | C52923 | 1uF | C_0402_1005Metric | 25V 1uF X5R ±10% 0402 Multilayer Ceramic Capacitors MLCC - SMD/SMT ROHS | Samsung Electro-Mechanics
24 | 1 | CL10A226MQ8NRNC | DNI | C3 | LCSC | C59461 | 22uF | C_0603_1608Metric | 6.3V 22uF X5R ±20% 0603 Multilayer Ceramic Capacitors MLCC - SMD/SMT ROHS | Samsung Electro-Mechanics
25 | 1 | AMS1117-3.3 | DNI | U2 | LCSC | C6186 | AMS1117-3.3 | SOT-223-3_TabPin2 | 72dB@(120Hz) 1A Fixed 3.3V Positive electrode 16V SOT-223 Voltage Regulators - Linear, Low Drop Out (LDO) Regulators ROHS | Advanced Monolithic Systems
26 | 1 | MCP4651T-503E/ST | DNI | U1 | LCSC | C627328 | MCP4651T-503E/ST | TSSOP14_MC_MCH | ±20% I2C 50k? 1.8V~5.5V TSSOP-14 Digital Potentiometers ROHS | Microchip Tech
27 | 1 | USBLC6-2SC6 | DNI | U3 | LCSC | C7519 | USBLC6-2SC6 | SOT-23-6 | 5A 17V 6V Unidirectional 5.25V SOT-23-6 ESD and Surge Protection (TVS/ESD) ROHS | STMicroelectronics
28 | 413 | XL-1615RGBC-RF |  | LED1,LED10,LED100,LED101,LED102,LED103,LED104,LED105,LED106,LED107,LED108,LED109,LED11,LED110,LED111,LED112,LED113,LED114,LED115,LED116,LED117,LED118,LED119,LED12,LED120,LED121,LED122,LED123,LED124,LED125,LED126,LED127,LED128,LED129,LED13,LED130,LED131,LED132,LED133,LED134,LED135,LED136,LED137,LED138,LED139,LED14,LED140,LED141,LED142,LED143,LED144,LED145,LED146,LED147,LED148,LED149,LED15,LED150,LED151,LED152,LED153,LED154,LED155,LED156,LED157,LED158,LED159,LED16,LED160,LED161,LED162,LED163,LED164,LED165,LED166,LED167,LED168,LED169,LED17,LED170,LED171,LED172,LED173,LED174,LED175,LED176,LED177,LED178,LED179,LED18,LED180,LED181,LED182,LED183,LED184,LED185,LED186,LED187,LED188,LED189,LED19,LED190,LED191,LED192,LED193,LED194,LED195,LED196,LED197,LED198,LED199,LED2,LED20,LED200,LED201,LED202,LED203,LED204,LED205,LED206,LED207,LED208,LED209,LED21,LED210,LED211,LED212,LED213,LED214,LED215,LED216,LED217,LED218,LED219,LED22,LED220,LED221,LED222,LED223,LED224,LED225,LED226,LED227,LED228,LED229,LED23,LED230,LED231,LED232,LED233,LED234,LED235,LED236,LED237,LED238,LED239,LED24,LED240,LED241,LED242,LED243,LED244,LED245,LED246,LED247,LED248,LED249,LED25,LED250,LED251,LED252,LED253,LED254,LED255,LED256,LED257,LED258,LED259,LED26,LED260,LED261,LED262,LED263,LED264,LED265,LED266,LED267,LED268,LED269,LED27,LED270,LED271,LED272,LED273,LED274,LED275,LED276,LED277,LED278,LED279,LED28,LED280,LED281,LED282,LED283,LED284,LED285,LED286,LED287,LED288,LED289,LED29,LED290,LED291,LED292,LED293,LED294,LED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 | LCSC | C965840 | LED_ARGB | LED_RGB_0606 | 0606 RGB LEDs ROHS | XINGLIGHT
END OF BOM

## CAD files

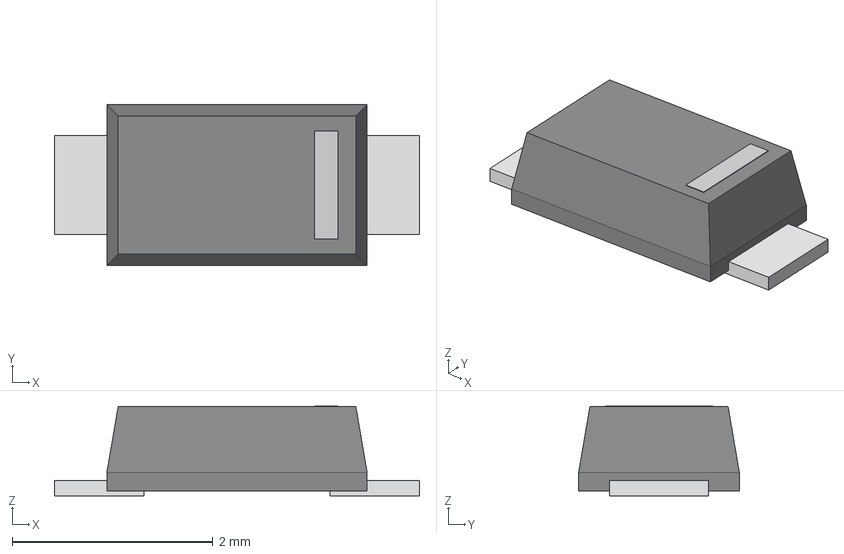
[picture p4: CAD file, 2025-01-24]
hardware/kicad/components/DIO_RB051MM_ROM.step
3.63 x 1.60 x 0.895 mm

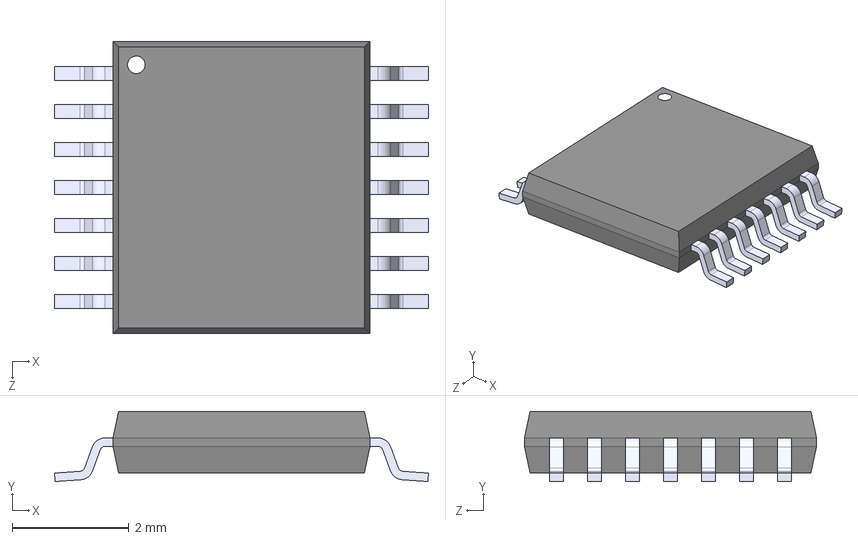
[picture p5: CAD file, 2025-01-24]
hardware/kicad/components/MCP4651T-503E_ST.STEP
6.40 x 1.20 x 5.00 mm

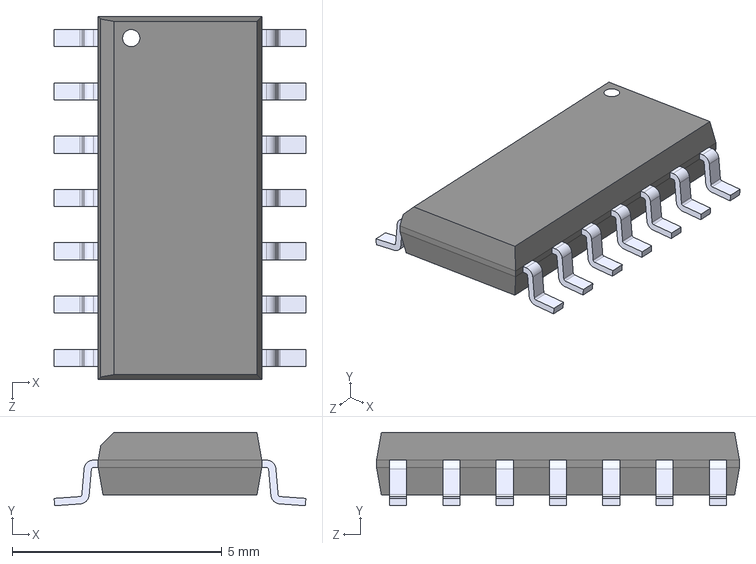
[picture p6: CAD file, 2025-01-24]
hardware/kicad/components/MCP4231T-103E_SL.step
6.00 x 1.75 x 8.65 mm

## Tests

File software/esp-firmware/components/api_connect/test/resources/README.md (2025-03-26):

data_north_V1_0_3.dat contains raw speed values as an array, where index 'i'
corresponds directly to the speed of led num 'i'. There are 326 elements in the
array, corresponding to the 326 LEDs on V1_0 hardware.

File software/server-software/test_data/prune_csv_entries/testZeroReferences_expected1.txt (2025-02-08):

[({'LED Number': '325', 'Freeway': 'Special', 'Direction': 'North', 'Longitude': '0', 'Latitude': '0', 'Tile': '0', 'openLr Code': '0', 'Free Flow Speed': '0', 'Reference': '0'}, [325]), 
({'LED Number': '326', 'Freeway': 'Special', 'Direction': 'North', 'Longitude': '0', 'Latitude': '0', 'Tile': '0', 'openLr Code': '0', 'Free Flow Speed': '0', 'Reference': '0'}, [326]), 
({'LED Number': '327', 'Freeway': 'Special', 'Direction': 'North', 'Longitude': '0', 'Latitude': '0', 'Tile': '0', 'openLr Code': '0', 'Free Flow Speed': '0', 'Reference': '0'}, [327]), 
({'LED Number': '329', 'Freeway': 'CA-1', 'Direction': 'North', 'Longitude': '33.687824', 'Latitude': '-118.039699', 'Tile': '22/721889/1679871', 'openLr Code': 'C6wQ5RfzSRp8TPQjDCEaDA==', 'Free Flow Speed': '56', 'Reference': ''}, [329, 328, 330]), 
({'LED Number': '331', 'Freeway': 'CA-126', 'Direction': 'North', 'Longitude': '34.270433', 'Latitude': '-119.219984', 'Tile': '22/708138/1671685', 'openLr Code': 'C6s1qBhdzRJFKgnoAnMSFw==', 'Free Flow Speed': '67', 'Reference': ''}, [331])]

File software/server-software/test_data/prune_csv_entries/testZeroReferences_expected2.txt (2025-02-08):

[({'LED Number': '325', 'Freeway': 'Special', 'Direction': 'South', 'Longitude': '0', 'Latitude': '0', 'Tile': '0', 'openLr Code': '0', 'Free Flow Speed': '0', 'Reference': '0'}, [325]), 
({'LED Number': '326', 'Freeway': 'Special', 'Direction': 'South', 'Longitude': '0', 'Latitude': '0', 'Tile': '0', 'openLr Code': '0', 'Free Flow Speed': '0', 'Reference': '0'}, [326]), 
({'LED Number': '327', 'Freeway': 'Special', 'Direction': 'South', 'Longitude': '0', 'Latitude': '0', 'Tile': '0', 'openLr Code': '0', 'Free Flow Speed': '0', 'Reference': '0'}, [327]), 
({'LED Number': '329', 'Freeway': 'CA-1', 'Direction': 'South', 'Longitude': '33.698618', 'Latitude': '-118.050083', 'Tile': '22/721768/1679720', 'openLr Code': 'C6wLQxf5AhpsTQwY86caHA==', 'Free Flow Speed': '56', 'Reference': ''}, [329, 328, 330])]

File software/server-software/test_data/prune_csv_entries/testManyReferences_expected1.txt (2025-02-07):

[({'LED Number': '1', 'Freeway': '101', 'Direction': 'North', 'Longitude': '34.45745', 'Latitude': '-119.980356', 'Tile': '22/699279/1669046', 'openLr Code': 'C6qyXxh+xwo7dOUMBr0KCA==', 'Free Flow Speed': '72', 'Reference': ''}, [1]), 
({'LED Number': '2', 'Freeway': '101', 'Direction': 'North', 'Longitude': '34.440808', 'Latitude': '-119.942794', 'Tile': '22/699717/1669281', 'openLr Code': 'C6q6qhh8Xwo5TO40BSkKCw==', 'Free Flow Speed': '72', 'Reference': ''}, [2, 3]), 
({'LED Number': '4', 'Freeway': '101', 'Direction': 'North', 'Longitude': '34.432527', 'Latitude': '-119.890335', 'Tile': '22/700328/1669398', 'openLr Code': 'C6rCBxh8lgo2QPA0/4sKCg==', 'Free Flow Speed': '72', 'Reference': ''}, [4, 5]), 
({'LED Number': '6', 'Freeway': '101', 'Direction': 'North', 'Longitude': '34.435107', 'Latitude': '-119.86683', 'Tile': '22/700602/1669361', 'openLr Code': 'C6rErhh9Ewo2F/pO/vMKBg==', 'Free Flow Speed': '71', 'Reference': ''}, [6]), 
({'LED Number': '7', 'Freeway': '101', 'Direction': 'North', 'Longitude': '34.43822', 'Latitude': '-119.846035', 'Tile': '22/700844/1669317', 'openLr Code': 'C6rJRxh9jQo3KPYi/voKBg==', 'Free Flow Speed': '68', 'Reference': ''}, [7]), 
({'LED Number': '8', 'Freeway': '101', 'Direction': 'North', 'Longitude': '34.441938', 'Latitude': '-119.807367', 'Tile': '22/701295/1669265', 'openLr Code': 'C6rQZhh9+wo3I/cw/60KBw==', 'Free Flow Speed': '68', 'Reference': ''}, [8]), 
({'LED Number': '9', 'Freeway': '101', 'Direction': 'North', 'Longitude': '34.442362', 'Latitude': '-119.787789', 'Tile': '22/701523/1669259', 'openLr Code': 'C6rUXxh91Ao5Ivd6AFMKBw==', 'Free Flow Speed': '70', 'Reference': ''}, [9]), 
({'LED Number': '10', 'Freeway': '101', 'Direction': 'North', 'Longitude': '34.44114', 'Latitude': '-119.764001', 'Tile': '22/701800/1669276', 'openLr Code': 'C6rWzxh9zgo5FfrEAA0KCQ==', 'Free Flow Speed': '70', 'Reference': ''}, [10]), 
({'LED Number': '11', 'Freeway': '101', 'Direction': 'North', 'Longitude': '34.436439', 'Latitude': '-119.751035', 'Tile': '22/701951/1669342', 'openLr Code': 'C6rYUxh8qQo8Bv7bAQYKDA==', 'Free Flow Speed': '67', 'Reference': ''}, [11]), 
({'LED Number': '12', 'Freeway': '101', 'Direction': 'North', 'Longitude': '34.427744', 'Latitude': '-119.731729', 'Tile': '22/702176/1669465', 'openLr Code': 'C6rdIhh7GQo5F/okAOYKCQ==', 'Free Flow Speed': '67', 'Reference': ''}, [12]), 
({'LED Number': '13', 'Freeway': '101', 'Direction': 'North', 'Longitude': '34.415428', 'Latitude': '-119.705894', 'Tile': '22/702477/1669639', 'openLr Code': 'C6rhExh4mQo5EfylAiUKCw==', 'Free Flow Speed': '65', 'Reference': ''}, [13]), 
({'LED Number': '14', 'Freeway': '101', 'Direction': 'North', 'Longitude': '34.419051', 'Latitude': '-119.688636', 'Tile': '22/702678/1669588', 'openLr Code': 'C6rk4xh6AAo3FPt0/o0KAw==', 'Free Flow Speed': '68', 'Reference': ''}, [14]), 
({'LED Number': '15', 'Freeway': '101', 'Direction': 'North', 'Longitude': '34.420254', 'Latitude': '-119.675055', 'Tile': '22/702836/1669571', 'openLr Code': 'C6rnWRh6Mgo2Ffq5/5YKBw==', 'Free Flow Speed': '63', 'Reference': ''}, [15]), 
({'LED Number': '16', 'Freeway': '101', 'Direction': 'North', 'Longitude': '34.420034', 'Latitude': '-119.645148', 'Tile': '22/703184/1669574', 'openLr Code': 'C6rtXxh6eQo3JvbrACkKCA==', 'Free Flow Speed': '64', 'Reference': ''}, [16]), 
({'LED Number': '17', 'Freeway': '101', 'Direction': 'North', 'Longitude': '34.421328', 'Latitude': '-119.627601', 'Tile': '22/703389/1669556', 'openLr Code': 'C6rweBh6QAo3G/lZAHwKCA==', 'Free Flow Speed': '62', 'Reference': ''}, [17]), 
({'LED Number': '18', 'Freeway': '101', 'Direction': 'North', 'Longitude': '34.421198', 'Latitude': '-119.600504', 'Tile': '22/703705/1669558', 'openLr Code': 'C6r18Rh5dQo5H/iIAXQKBw==', 'Free Flow Speed': '66', 'Reference': ''}, [18]), 
({'LED Number': '19', 'Freeway': '101', 'Direction': 'North', 'Longitude': '34.415903', 'Latitude': '-119.573411', 'Tile': '22/704020/1669632', 'openLr Code': 'C6r7fRh4uwo8MvQZAZAKCQ==', 'Free Flow Speed': '66', 'Reference': ''}, [19]), 
({'LED Number': '20', 'Freeway': '101', 'Direction': 'North', 'Longitude': '34.409338', 'Latitude': '-119.550793', 'Tile': '22/704284/1669725', 'openLr Code': 'C6r/zRh3JQo5Kva/A2cKCw==', 'Free Flow Speed': '67', 'Reference': ''}, [20, 21]), 
({'LED Number': '22', 'Freeway': '101', 'Direction': 'North', 'Longitude': '34.392319', 'Latitude': '-119.508109', 'Tile': '22/704781/1669966', 'openLr Code': 'C6sFZBh0cQo5F/vwAyEKDQ==', 'Free Flow Speed': '72', 'Reference': ''}, [22]), 
({'LED Number': '23', 'Freeway': '101', 'Direction': 'North', 'Longitude': '34.388729', 'Latitude': '-119.49887', 'Tile': '22/704889/1670016', 'openLr Code': 'C6sH2xhzqQo5Fvq2Aa0KCQ==', 'Free Flow Speed': '71', 'Reference': ''}, [23]), 
({'LED Number': '24', 'Freeway': '101', 'Direction': 'North', 'Longitude': '34.377145', 'Latitude': '-119.479137', 'Tile': '22/705119/1670180', 'openLr Code': 'C6sKchhx+Ao3Cv2ZALgKTHk=', 'Free Flow Speed': '68', 'Reference': ''}, [24]), 
({'LED Number': '25', 'Freeway': '101', 'Direction': 'North', 'Longitude': '34.369825', 'Latitude': '-119.454388', 'Tile': '22/705407/1670283', 'openLr Code': 'C6smuBhhIgo609eoGI0KPTP2UQXDCjxB8vUGiQosFQ==', 'Free Flow Speed': '71', 'Reference': ''}, [25, 26, 27, 28, 29, 30, 31, 32])]

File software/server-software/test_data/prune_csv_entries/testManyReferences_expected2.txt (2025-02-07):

[({'LED Number': '1', 'Freeway': '101', 'Direction': 'South', 'Longitude': '34.45657', 'Latitude': '-119.975818', 'Tile': '22/699332/1669058', 'openLr Code': 'C6qqoBiBTgooUhIs+XoKGg==', 'Free Flow Speed': '73', 'Reference': ''}, [1]), 
({'LED Number': '2', 'Freeway': '101', 'Direction': 'South', 'Longitude': '34.438392', 'Latitude': '-119.928052', 'Tile': '22/699888/1669315', 'openLr Code': 'C6qzGBh+QwoqUxPP+5UKFw==', 'Free Flow Speed': '73', 'Reference': ''}, [2, 3]), 
({'LED Number': '4', 'Freeway': '101', 'Direction': 'South', 'Longitude': '34.432419', 'Latitude': '-119.881319', 'Tile': '22/700433/1669399', 'openLr Code': 'C6q8Uxh8NAooOg5WARAKFw==', 'Free Flow Speed': '72', 'Reference': ''}, [4, 5]), 
({'LED Number': '6', 'Freeway': '101', 'Direction': 'South', 'Longitude': '34.437084', 'Latitude': '-119.855965', 'Tile': '22/700728/1669333', 'openLr Code': 'C6rDAhh8swomHwe4AS4KFw==', 'Free Flow Speed': '70', 'Reference': ''}, [6]), 
({'LED Number': '7', 'Freeway': '101', 'Direction': 'South', 'Longitude': '34.439495', 'Latitude': '-119.83183', 'Tile': '22/701009/1669299', 'openLr Code': 'C6rGmxh9QAonHAcWALUKFw==', 'Free Flow Speed': '68', 'Reference': ''}, [7]), 
({'LED Number': '8', 'Freeway': '101', 'Direction': 'South', 'Longitude': '34.441548', 'Latitude': '-119.812175', 'Tile': '22/701238/1669270', 'openLr Code': 'C6rJ6Bh9lAonJwnXAKcKGA==', 'Free Flow Speed': '65', 'Reference': ''}, [8]), 
({'LED Number': '9', 'Freeway': '101', 'Direction': 'South', 'Longitude': '34.442156', 'Latitude': '-119.790265', 'Tile': '22/701494/1669262', 'openLr Code': 'C6rOfhh94gooHAcBADYKGA==', 'Free Flow Speed': '68', 'Reference': ''}, [9]), 
({'LED Number': '10', 'Freeway': '101', 'Direction': 'South', 'Longitude': '34.441096', 'Latitude': '-119.761235', 'Tile': '22/701832/1669277', 'openLr Code': 'C6rU2xh9xAooFwWF/0EKGw==', 'Free Flow Speed': '67', 'Reference': ''}, [10]), 
({'LED Number': '11', 'Freeway': '101', 'Direction': 'South', 'Longitude': '34.436037', 'Latitude': '-119.750865', 'Tile': '22/701953/1669348', 'openLr Code': 'C6rXbhh9awosCgHb/lkKHA==', 'Free Flow Speed': '67', 'Reference': ''}, [11]), 
({'LED Number': '12', 'Freeway': '101', 'Direction': 'South', 'Longitude': '34.42939', 'Latitude': '-119.741085', 'Tile': '22/702067/1669442', 'openLr Code': 'C6rYSxh8pgosIwez/QwKGQ==', 'Free Flow Speed': '69', 'Reference': ''}, [12]), 
({'LED Number': '13', 'Freeway': '101', 'Direction': 'South', 'Longitude': '34.418831', 'Latitude': '-119.711322', 'Tile': '22/702414/1669591', 'openLr Code': 'C6rd9Rh6sAorGgUA/HAKHA==', 'Free Flow Speed': '69', 'Reference': ''}, [13]), 
({'LED Number': '14', 'Freeway': '101', 'Direction': 'South', 'Longitude': '34.414508', 'Latitude': '-119.693617', 'Tile': '22/702620/1669652', 'openLr Code': 'C6riFBh4tgokEwOkAnsKFw==', 'Free Flow Speed': '66', 'Reference': ''}, [14]), 
({'LED Number': '15', 'Freeway': '101', 'Direction': 'South', 'Longitude': '34.420217', 'Latitude': '-119.678333', 'Tile': '22/702798/1669572', 'openLr Code': 'C6rjxxh53gonGAYfADIKFg==', 'Free Flow Speed': '66', 'Reference': ''}, [15]), 
({'LED Number': '16', 'Freeway': '101', 'Direction': 'South', 'Longitude': '34.422217', 'Latitude': '-119.662458', 'Tile': '22/702983/1669543', 'openLr Code': 'C6rmoRh59QomOA1LAOUKFg==', 'Free Flow Speed': '63', 'Reference': ''}, [16]), 
({'LED Number': '17', 'Freeway': '101', 'Direction': 'South', 'Longitude': '34.422438', 'Latitude': '-119.632034', 'Tile': '22/703337/1669540', 'openLr Code': 'C6rs0xh6YAomEgSQ/3UKGA==', 'Free Flow Speed': '59', 'Reference': ''}, [17]), 
({'LED Number': '18', 'Freeway': '101', 'Direction': 'South', 'Longitude': '34.421056', 'Latitude': '-119.603288', 'Tile': '22/703672/1669560', 'openLr Code': 'C6rxihh6OQopHAbJ/xsKGQ==', 'Free Flow Speed': '65', 'Reference': ''}, [18]), 
({'LED Number': '19', 'Freeway': '101', 'Direction': 'South', 'Longitude': '34.416516', 'Latitude': '-119.564965', 'Tile': '22/704119/1669624', 'openLr Code': 'C6r3TBh5MwopPg23/CEKGA==', 'Free Flow Speed': '68', 'Reference': ''}, [19, 20]), 
({'LED Number': '21', 'Freeway': '101', 'Direction': 'South', 'Longitude': '34.402259', 'Latitude': '-119.521348', 'Tile': '22/704627/1669825', 'openLr Code': 'C6r9sBh3ZQooPg1v+0EKHA==', 'Free Flow Speed': '70', 'Reference': ''}, [21, 22]), 
({'LED Number': '23', 'Freeway': '101', 'Direction': 'South', 'Longitude': '34.385769', 'Latitude': '-119.490382', 'Tile': '22/704988/1670058', 'openLr Code': 'C6sGkhh0BQoqGAUB/YMKHQ==', 'Free Flow Speed': '68', 'Reference': ''}, [23]), 
({'LED Number': '24', 'Freeway': '101', 'Direction': 'South', 'Longitude': '34.376582', 'Latitude': '-119.478694', 'Tile': '22/705124/1670188', 'openLr Code': 'C6sI5xhy3AotEQNA/f0KN08=', 'Free Flow Speed': '71', 'Reference': ''}, [24]), 
({'LED Number': '25', 'Freeway': '101', 'Direction': 'South', 'Longitude': '34.374644', 'Latitude': '-119.461922', 'Tile': '22/705319/1670215', 'openLr Code': 'C6sKahhx7AonRg1++FUKGA==', 'Free Flow Speed': '71', 'Reference': ''}, [25, 26]), 
({'LED Number': '27', 'Freeway': '101', 'Direction': 'South', 'Longitude': '34.335602', 'Latitude': '-119.404383', 'Tile': '22/705990/1670766', 'openLr Code': 'C6sQtBhuWgoo9C6b49kKKiQIg/1dChg=', 'Free Flow Speed': '71', 'Reference': ''}, [27, 28, 29, 30, 31, 32])]

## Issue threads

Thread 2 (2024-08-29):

Missing BOM

jdbaptista, 2024-08-29:
Additionally, 3d models for LEDs would be a good addition to be able to see spacing.

aidan-9880, 2024-08-29:
Check in hardware/kicad/jlcpcb/production_files. Last column has LCSC part numbers. 3D models are all in hardware/kicad/map_lbr.pretty, 0606.STEP should be the LED. Kicad probably "forgot" the correct path for the LED when I uploaded the files, it tends to do that.

Closed 2024-08-31.

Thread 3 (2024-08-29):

I2C lines pulled to 5v instead of 3.3v

jdbaptista, 2024-08-29:
Currently, the I2C lines are pulled up to 5v, which I don't think the esp32 GPIO lines can handle. The matrix driver ICs can operate anywhere from 2.7-5.5v on data input lines when Vcc = 5v, so I think we can just change the 5v pullup to 3.3v.

Also, the resistors on the matrix driver data lines don't match the typical application circuit in the [datasheet](https://www.lumissil.com/assets/pdf/core/IS31FL3741A_DS.pdf) and are duplicated (present in matrix 1,2,3) for the shared SDA and SCL lines; I think they should be present only once.

I'm writing this as an issue instead of just making a commit because I don't want to break anything that was done intentionally. Any feedback before I make the change?

aidan-9880, 2024-08-29:
They should be pulled to 3.3v, that's my mistake. Used the wrong power symbol on accident. The resistor values and number of them is fine, 3 4.7k ohm in parallel = about 1600 ohms, around where it needs to be according to https://www.ti.com/lit/an/slva689/slva689.pdf (page 3). The i2c tracks are relatively long = high capacitance, so I didn't want to go too high.

I have also made a few minor changes since I uploaded those files, will update the kicad files tomorrow with the final version when I'm in the office.

aidan-9880, 2024-08-30:
Switched to one 2k ohm resistor on each line, pulled to 3.3v. Also pulled the other LED driver resistors (on interrupt and shutdown pins) to 3.3v.

Closed 2024-08-31.

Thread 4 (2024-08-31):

GPIO pins 34/35 are input only

jdbaptista, 2024-08-31:
See the [reference manual](https://www.espressif.com/sites/default/files/documentation/esp32_technical_reference_manual_en.pdf#iomuxgpio). This is not a problem for the interrupt pin, but SBD3 should be moved to a lower GPIO pin.

jdbaptista, 2024-08-31:
Solved with commit [3c00f40](https://github.com/zinkwazi/traffic-pcb-sb/commit/3c00f40fd7b06f7c6e74ef31b346b67b156fcc27).

Closed 2024-09-03.

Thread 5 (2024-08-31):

ESP32 Strapping pins need well-defined values

jdbaptista, 2024-08-31:
See [this discussion](https://esp32.com/viewtopic.php?t=5970) and [3 Boot Configurations](https://www.espressif.com/sites/default/files/documentation/esp32_datasheet_en.pdf) of the datasheet. I don't know much about this but came across it and will do more research soon.

jdbaptista, 2024-08-31:
These may configure things that don't matter for our application? The only one we definitely need to enable is U0TXD printing (I think).

jdbaptista, 2024-09-01:
Additionally, GPIO6-11 and GPIO16-17 are not recommended for use. See [2 Pins](https://www.espressif.com/sites/default/files/documentation/esp32_datasheet_en.pdf) of the datasheet. I'm sure they can be used and we will probably have to but it is good to look more into why this recommendation exists.

jdbaptista, 2024-09-02:
Strapping of MTDO (IO15) and GPIO5 don't matter because they only configure the initial timing of the SDIO slave, which is not used in our application and can be changed after booting. MTDO also configures debug logging over U0TXD during boot, which we don't care about.

GPIO0 and GPIO2 are used for programming, which is setup properly right now.

The only pin that is problematic is MTDI (IO12) which controls the voltage to the wroom-32 SPI flash module and needs to be pulled low. I am going to move interrupt lines to the input only GPIO lines and move a few things around to set MTDI and MTDO to NC (ie. high impedance). This will enable debug logging during boot and provide the correct power to the SPI flash module.

jdbaptista, 2024-09-04:
Fixed with commit 9996acc.

Closed 2024-09-04.

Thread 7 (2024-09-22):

Enable JTAG support

jdbaptista, 2024-09-22:
Making a pinout for the JTAG pins (MTDI, MTDO, etc.) and fixing strapping issues with time delay pullups / pulldowns should enable this.
Example circuit (that I think is correct):

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

When R1 >> R2 and the transistor is closed, Vout = Vin (R2 / (R1 + R2)) ~= 0. When the transistor is open, Vout = Vin.
The same idea with a pullup resistor should be even easier, as no voltage divider is necessary.

jdbaptista, 2024-09-23:
The following LTSpice circuits show example implementations. Note that the NOT gate in the circuit driving the output low can be replaced with a depletion mode mosfet (on when Vgs is low, off when Vgs is high). Work still needs to be done to determine the proper RC time constants for each circuit and resistor values to make sure the current is not too high.

Drive low during RC charge up using nmos transistor (and not gate):
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

Drive high during RC charge up using pmos transistor:
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

jdbaptista, 2024-09-23:
The [esp32-wroom-32 datasheet](https://www.espressif.com/sites/default/files/documentation/esp32-wroom-32_datasheet_en.pdf) specifies a 0ms setup time and 1ms hold time for strapping pins when CHIP_PU/EN goes high (pg. 11). A high level input voltage is defined to be above 0.75 * VDD = 0.75 * 3.3 = 2.475V, and a low level input voltage is defined to be below 0.25 * VDD = 0.25 * 3.3 = 0.825V. Using [this](https://www.digikey.com/en/products/detail/microchip-technology/DN3135K1-G/4902754) n-channel depletion-mode transistor with Vth = -1.5v, ie. 3.3 - 1.5 = 1.8v capacitor charge, a hold of 3ms requires a time delay constant of a little over 3ms, which would charge to 3.3 * 0.632 = 2.0856 in 3ms. For a 1ms minimum hold time, a 3ms time constant will suffice. This can be achieved with T = R * C = 3k * 1u = 3ms. To be safe, the resistor can be set to 5k for a hold time of 5ms.

For driving low, as the low level input voltage is below 0.825V, the resistors should satisfy 0.825 < 3.3 * (R2 / (R3 + R2)). The input device should be able to keep the input voltage above 2.475V at a high logic level, so the voltage drop across R3 must be Vd < 0.825V when R2 is disconnected, which means that the input device must be able to source some current. To avoid this, an op-amp unity gain buffer should be used before the R3/R2 voltage divider. With an op-amp handling current issues, the resistor values can be R3 = 30k and R2 = 5k, which equates to an output voltage of 0.47V.

For driving high, the same RC delay circuit can be used and R2 can be sufficiently high (ie. 30k) to reduce current draw. An op-amp should be used to separate the device from the JTAG driving device.

jdbaptista, 2024-09-24:
It turns out that depletion-mode pmos transistors (which is what would be necessary to drive the circuit low) are not common components and it will be better to simply use the inverter as shown in the LTSpice example. [this](https://www.digikey.com/en/products/detail/infineon-technologies/IRF7341TRPBFXTMA1/20841825) IC contains 2 enhancement mode nmos transistors with a threshold voltage of Vth = 1.0V. The LTSpice graph shows that a 10k, 1u RC combo should satisfy the hold time requirement even at only 1V.

The drive up circuit uses [this](https://www.digikey.com/en/products/detail/nexperia-usa-inc/BSS84AK-215/2779831) pmos enhancement mode mosfet, which has a Vth of between -1.1 to -2.1V. In the worst case, the mosfet will turn on after the capacitor charges to just 1.2V, which can still be met with the RC combo above.

jdbaptista, 2024-09-24:
See commit 56c4915 on issue_7 branch. Any thoughts on the design before I route it?

jdbaptista, 2024-11-21:
An alternative solution using tri-state buffers was implemented instead, which was added in commit [fbb4deb](https://github.com/zinkwazi/traffic-pcb-sb/commit/fbb4deb815bba9cbfc3ac08e3ee8a7c09c747f4e).

Closed 2024-11-21.

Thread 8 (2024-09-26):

Seemingly random error in http_client_perform

jdbaptista, 2024-09-26:
I made an espressif forum [post](https://www.esp32.com/viewtopic.php?f=13&t=42017) about the issue.

jdbaptista, 2024-09-26:
Increased the http client size buffer and solved this in commit 6b2a8f8.

Closed 2024-09-26.

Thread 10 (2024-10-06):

I2C gatekeeper performs arbitrary callbacks

jdbaptista, 2024-10-06:
This is insecure because a malicious task can take control of the I2C task, potentially preventing it from operating normally or worse. A more secure error handling method is through the use of a mailbox for each task implemented with task notifications. The only downside to this is that the error handling may not be performed automatically, and the calling task must block on the mailbox if immediate error handling needs to occur.

jdbaptista, 2024-11-05:
This has been fixed in commit 36c79cb by replacing the callback feature with a simpler task notification method. The only downside to this is that error handling is delayed by however long the calling task takes to check the task notification. This is not a big issue with the current codebase because error handling boils down to telling the user an error has occurred, which is not time sensitive.

Closed 2024-11-05.

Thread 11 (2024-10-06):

LED hardware numbers aren't logical with respect to the datasheet

jdbaptista, 2024-10-06:
~~ROWS are mapped backward on the CS matrix pins, causing the numbering system to be revered with respect to the datasheet~~. COLUMNS are split into two blocks, making things more confusing. These hardware numbers will be mapped properly in software, however the numbering differences makes the process error-prone. If there is another revision of the board, I think the LED numbers should be revised to make more sense with the datasheet.

jdbaptista, 2024-10-06:
Numbering should also be increasing by 1 on the ROW side, and spill over on the COLUMN side.

jdbaptista, 2024-10-06:
Pinout is different for each matrix, they should be standardized.

zinkwazi, 2024-12-07:
You only need to generate the LED matrix map once so, while it's not ideal, we cab live with this and fix it on the next projsect - Bay Area Freeways, anyone :)

aidan-9880, 2024-12-17:
Only reason for this was to make routing the matrix easier. Would've gotten pretty messy if stuff was crossing over everywhere. Definitely possible to change but not without a lot of rerouting.

jdbaptista, 2025-01-28:
Closing because nothing is logical anyway and there is no quick way to fix this without breaking mappings. Definitely something to keep in mind for future projects if we decide to make similar boards.

Closed 2025-01-28.

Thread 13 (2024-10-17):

esp_http_client_perform is failing when called with the same config in a new stack frame

jdbaptista, 2024-10-17:
Not sure why this is happening yet, but two requests to either the same or different LEDs fails.

jdbaptista, 2024-10-18:
This is caused by stack smashing in the http event handler with the messy logic I wrote and didn't effectively test, whoops. Moral of this story is to test code and turn on stack canaries while testing.
```
I (2354) esp-x509-crt-bundle: Certificate validated
E (3594) TomTom: tomtomRequestPerform(464): recieved an error from the http client event handler
E (3594) TomTom: tomtomRequestSpeed(182): failed to perform API request

Stack smashing protect failure!

Backtrace: 0x4008182e:0x3ffba630 0x40089719:0x3ffba650 0x400811de:0x3ffba670 0x400d7865:0x3ffba690 0x400d719d:0x3ffba770 0x401705b3:0x3ffba880 0x4008a2d1:0x3ffba8b0
```

jdbaptista, 2024-10-19:
Stack smashing was due to an off by one error in URL_LENGTH, which is now fixed as of cf6884a.

Closed 2024-10-19.

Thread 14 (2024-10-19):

TomTom states that some LED locations are not close enough to their road segment

jdbaptista, 2024-10-19:

jdbaptista, 2024-11-05:
This was fixed some time ago, or at least hasn't come up since commit 6d4943e.

Closed 2024-11-05.

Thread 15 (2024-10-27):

The UART transmit lines are connected transmit to transmit and receive to receive

jdbaptista, 2024-10-27:

jdbaptista, 2024-11-05:
Fixed in commit [05474ab](https://github.com/zinkwazi/traffic-pcb-sb/commit/05474ab0232cd3fe631dd34bcb2121c668cc349e).

Closed 2024-11-05.

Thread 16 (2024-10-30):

South LED locations jump from 122 to 125

jdbaptista, 2024-10-30:

jdbaptista, 2024-10-30:
led 142 is duplicated, as well.

jdbaptista, 2024-10-30:
fixed in commit 19f048.

Closed 2024-10-30.

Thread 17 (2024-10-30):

Hardwired LEDs are too bright

jdbaptista, 2024-10-30:

jdbaptista, 2024-11-18:
The error LED is alright in terms of brightness, with the datasheet stating that the brightness is 95 to 113mcd (millicandela (thanks chatgpt)) at 20mA. Assuming the LED is at the average of 104mcd at 20mA, and knowing that the current of the circuit is 3.3v / 470ohm = 7.02mA, and using the brightness curve provided in the [datasheet](https://www.lcsc.com/datasheet/lcsc_datasheet_1806151129_Hubei-KENTO-Elec-KT-0805Y_C2296.pdf), we know that the brighness of the LED in the circuit is around 40% of 104mcd. That is, the LED has a brighness of ~42mcd, which serves as a guideline for the LEDs that are too bright.

jdbaptista, 2024-11-18:
The [LEDs](https://www.lcsc.com/datasheet/lcsc_datasheet_2305091500_Hubei-KENTO-Elec-KT-0805W_C34499.pdf) currently on the PCB have a stated brightness of about 350mcd at 5mA, which is quite bright and doesn't allow for much room to lower the brightness to something like 50-100mcd. I recommend switching the LEDs for another component that is less bright.

jdbaptista, 2024-11-18:
[This](https://www.lcsc.com/product-detail/LED-Indication-Discrete_ROHM-Semicon-SMLMN2WB1CW1_C2992528.html) LED is only 56-140mcd at 5mA, which should be a manageable brightness. The variance is higher than what I assumed it would be for most LEDs, which leads me to believe that the error led could be made brighter (probably brought to 20mA to have a similar average brightness (98mcd vs 104mcd). I'm not sure how color difference between red and white affects how humans actually perceive brightness, but this should be better than 42mcd and (22mA -> 1400mcd), which is what is currently on the board.

jdbaptista, 2024-11-19:
The new LED can be made 63mcd at a typical 140mcd at 5mA by supplying it with 2mA, which corresponds to a 275ohm resistor for 3.3V and 1.125kohm for 5v. This calculation accounts for forward voltage of the LED.

jdbaptista, 2024-11-19:
Fixed (hopefully) in commit c7a8e9a.

Closed 2024-11-19.

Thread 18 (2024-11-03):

esp-tls sometimes can't resolve hostname

jdbaptista, 2024-11-03:
This issue seems to occur mostly at startup, which makes me believe this should be something that can be fixed by retrying in the dot worker task.

```
E (5547) esp-tls: couldn't get hostname for :api.tomtom.com: getaddrinfo() returns 202, addrinfo=0x0
E (5557) transport_base: Failed to open a new connection: 32769
E (5557) HTTP_CLIENT: Connection failed, sock < 0
E (5567) TomTom: tomtomRequestPerform(521): failed to make HTTPS request to TomTom
E (5587) TomTom: tomtomRequestSpeed(195): failed to perform API request
E (5587) dot_worker: failed to request southbound led 6 speed from TomTom
```

jdbaptista, 2024-11-09:
See this [forum post](https://www.esp32.com/viewtopic.php?t=39788), stating that this is likely due to power supply issues.

jdbaptista, 2024-11-09:
This has been mitigated in commit d425abd by simply retrying the connection some configurable number of times, but given that the problem is probabilistic it is still technically an issue.

jdbaptista, 2024-11-18:
I don't think this will be a problem further, it hasn't shown up since implementing the change above.

Closed 2024-11-18.

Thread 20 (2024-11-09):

east led is dim while esp32 is initializing

jdbaptista, 2024-11-09:
The led should be moved to a different pin that is constant low during initialization.

jdbaptista, 2024-11-18:
This is likely because the pin it is connected to is a strapping pin that is high impedance during startup. This can be fixed with a pullup or pulldown resistor (probably), but it is easier to move it to a non-strapping pin (which is likely to fix the issue). This was done in commit 354cfec.

Closed 2024-11-18.

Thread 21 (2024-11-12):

main makes i2c requests on startup, which can cause a task notification

jdbaptista, 2024-11-12:
This became evident after some changes to the led numbering system. After requesting to clear an LED that doesn't exist, the I2C gatekeeper sent a task notification to main. This should be the intended behavior, but these notifications cause unintended behavior due to the fact that main understands task notifications to mean that the direction button has been pressed.

jdbaptista, 2024-11-13:
Fixed in commit e0ade50, which adds blocking on I2C gatekeeper task notifications.

Closed 2024-11-13.

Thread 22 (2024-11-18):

Firmware does not try to reconnect wifi if disconnected

jdbaptista, 2024-11-18:

jdbaptista, 2024-11-25:
This is potentially fixed in commit [8261feb](https://github.com/zinkwazi/traffic-pcb-sb/commit/8261feb582217063b7ec0e15dca26be8c8ae93d0), but the functionality is not yet tested.

jdbaptista, 2024-12-13:
Fixed in commit c1861d3.

Closed 2024-12-13.

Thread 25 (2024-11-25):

Add LEDs to 126 segment

zinkwazi, 2024-11-25:
Add LEDs to the short 126 section between the 101 and the 118 to close that loop.

jdbaptista, 2024-12-20:
Added in commit d8795dd.

jdbaptista, 2024-12-20:
Needs software support and openLR code mapping.

jdbaptista, 2025-01-28:
Closing because this is now part of a larger amount of work that will be completed for V2_0.

Closed 2025-01-28.

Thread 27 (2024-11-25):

Screen print tweaks

zinkwazi, 2024-11-25:
- Remove the pointer lines from the current labels.
- Move Outside Open's label closer to the star and make the star bigger :)
- Add labels for:
  - Long Beach
  - Glendale
  - Goleta :)
  - Malibu
  - Santa Monica
  - Ventura
  - Anaheim
  - Remove the vertical South Western / Western avenue and label the 110.
  - Label Anacapa, and Santa Cruz islands

Don't be too concerned about being super accurate on the labels, this is a pretty broad strokes map.

jdbaptista, 2024-12-03:
I'm not sure how the silkscreen for the roads was created nor how I can modify it, so I'll ask Aidan about if removing the vertical western avenue is possible easily. I will make a PR for the other stuff shortly

aidan-9880, 2024-12-17:
I removed Western Ave in 30108bec5a281ee872067c4caef2b5d870d5c923. Should be good to close this.

zinkwazi, 2024-12-17:
Nice!

Closed 2024-12-17.

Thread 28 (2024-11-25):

Architectural code changes

zinkwazi, 2024-11-25:
As we plan for version 2, I want to suggest a new approach and features that will improve scalability, efficiency, and functionality.

    **Server-Side Data Processing:**
        Replace the current board-side TomTom querying system with a server-side Python application.
        The server will handle API calls to TomTom, aggregate traffic data, and format it into a concise payload for each board.
        This reduces API call costs and eliminates the need for each board to have a unique TomTom API key.

    **Unique Board Identification:**
        Boards will present a unique ID during each data request.
        Use the ESP32’s MAC address or whatever is available

    **Optimized Data Transmission:**
        Instead of sending data for every LED, the server will provide a compact list of LED states (e.g., R, B, G) in a serialized format.
        Use efficient protocols such as MQTT or compressed JSON to reduce overhead.

    **Memory Optimization on ESP32:**
        Reduce storage needs on the ESP32 by:
            Offloading data logic to the server (e.g., traffic segment mapping).
            Storing only LED states and logic for rendering them.
        This frees up space to support additional LEDs.

    **Boot Behavior and Refresh Cycle:**
        On boot, the board will display north-to-south traffic conditions automatically.
        Implement a 5-minute interval to refresh and switch to displaying south-to-north traffic conditions.

jdbaptista, 2024-12-06:
So I've thought of a few options for supporting LED animations. The simplest and probably quickest is to store the PCB coordinates of the LEDs and calculate the order in which the LEDs should be turned on based on distance from some animation curve. For example, for a flow from top left to bottom right a straight line can be defined by the equation $y = tan(\theta)x$, with the dot product a point to a vector defining the line giving a signed distance $D=-sin(\theta)x+cos(\theta)y$. The D value of all LEDs can then be sorted and given to the I2C gatekeeper in that order. Calculations can be done to find the D value of many other types of lines and curves using linear algebra, however that may be difficult.

An alternative that is more in line with an adjacency matrix and will probably allow for a bit more flexibility is to use a variable precision tree to store points. This kind of tree works by splitting the coordinate space into a few partitions (think 4) and splitting those partitions further until only one LED is contained in any node of the tree. This is efficient when there is a lot of sparsity on the grid. This method is much more difficult for arbitrary angle sweeping animations, but should be quite fast and easy for animations in line with the grid used to define the LED coordinates. Even then, there will be more work to implement this method than the one discussed above, which is just more math heavy for adding new animation curves.

One other option is to use linked lists for each row and column in the adjacency matrix, with each list containing which LEDs are in that row or column. This should be easier to implement than the variable precision tree, however takes up double the amount of space necessary to store the data. With the amount of space used to store this, animations can be precomputed using the first method and stored directly in the program.

zinkwazi, 2024-12-07:
I like the first option - distance based calculations on an animation curve, but there may be a computational limit on the ESP32 that we'd have to experiment with.

-     Flexibility: This method would support a wide range of animations, including waves, flows, and sweeping effects. It's adaptable to straight l;ines, diagonal waves, and even simple curves.

-     Simplicity: It's the easiest to implement compared to the quadtree or linked list methods.

-     Low Memory Footprint: Only requires storing the cooordinates of LEDs and performing calculations dynamically.

-     Pre computation: Sorting dynamically can be computationally expensive, precomputing the sorted order for common curves can help mitigate this.

zinkwazi, 2024-12-07:
Use a LUT to store each LED's segment association and coordinates.
This way you'll be able to do the animations because the matrix will have the adjacency.

leds = [
    {"id": 0, "segment": "I-5_North", "x": 10, "y": 20},
    {"id": 1, "segment": "I-5_North", "x": 12, "y": 22},
    {"id": 2, "segment": "I-405_South", "x": 50, "y": 60},
    {"id": 3, "segment": "NULL", "x": 52, "y": 60}, //no LED at this location
    # ... continue for all LEDs
]
The array may contain additional details but you get the idea.

jdbaptista, 2025-04-15:
Aside from unique board identification, this is complete! V2_0 is a very nice board so far :)

Closed 2025-04-15.

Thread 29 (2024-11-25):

v2 Stretch goals

zinkwazi, 2024-11-25:
**Stretch Goal for V2**

    **Ambient Brightness Adjustment:**
        Integrate a photoresistor to measure ambient light.
        Adjust LED brightness dynamically based on the surrounding light to improve comfort in low-light environments.

    **Additional LEDs:**
        Add LEDs for the 10 freeway.
        Add LEDs for the 110 freeway.

jdbaptista, 2024-12-20:
Unfortunately, I think the additional LEDs will have to wait for V3 simply due to time constraints

jdbaptista, 2025-01-02:
I believe that adding a new matrix driver is possible and will not draw too much power. The USB-C specification provides a minimum of 1.5A if both the source and drain receptacles are USB-C receptacles. I'll assume this to be the maximum we can draw without any modification to the circuit (source: https://hackaday.com/2022/12/06/usb-c-introduction-for-hackers/). The article actually states that the circuit we have now is configured to draw 3A, but its better to be safe.

The current of each CS line on the matrix drivers outputs a peak current of `Iout(peak) = 18.93mA * (GCC / 256) * (SL / 256)` where GCC is the global current control register and SL is the scaling register for the LED. There are 39 CS lines on each driver and the maximum safe GCC that the LEDs can handle at SL = 256 is 0x80 (ie. 128). Thus the maximum draw of an individual driver should be a little over `I = 39 * 18.93mA * (128 / 256) = 369.135mA. I'm not sure how much current the IC itself pulls, but we can round up to 400mA to be safe. With 4 drivers, this is a total of 1.2A@5V = 6 watts, leaving 1.5 watts for the rest of the circuitry. The biggest draw from the rest of the board is the ESP32, which specifies a recommended power supply output current of 500mA at 3.3V (1.65 watts).

The total here is 7.65 watts, which is slightly over the maximum. However, most of the time only one of the three LEDs for a particular location is on at a time, meaning the 4 drivers should realistically be pulling slightly over 2 watts at any time. If we ensure in the code that the sum of SL of the three registers does not exceed (2/3) of the maximum, the power draw from the drivers should only be 4 watts, bringing the total draw of the ESP32 and LEDs to 5.65 watts. There should be enough power for the rest of the circuitry, especially if the LEDs are not blasting at the maximum current they can handle.

jdbaptista, 2025-01-03:
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
This is what I will be implementing for new matrix boundaries. I will try to load balance the matrices a little bit so that future additions can be routed from the closest matrix driver instead of only from the new matrix (which would require cross-boundary lines).

zinkwazi, 2025-01-04:
Nice, great idea!

zinkwazi, 2025-01-04:
If we get really ambitious in the future, we can switch to a 5W power supply like Adafruit does for driving up  to 25K LEDs:
https://www.adafruit.com/product/1466

jdbaptista, 2025-04-24:
Added dynamic brightness adjustment in v0.8.0 1fdbe1c25b60d4e45bcf0b8c9c31f349a9717b69. This is now complete!

Closed 2025-04-24.

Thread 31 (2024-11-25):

Shift cardinal direction section down

zinkwazi, 2024-11-25:
Move the cardinal direction section down by 1cm so that it is more centered between the island and Goleta.

jdbaptista, 2024-12-16:
Fixed in commit [bfbb140](https://github.com/zinkwazi/traffic-pcb-sb/commit/bfbb1401b9d2f9219475a54141f6c9840f08c243).

Closed 2024-12-16.

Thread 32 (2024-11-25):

LED key

zinkwazi, 2024-11-25:
Add a short row of LEDs on the bottom with a key labeling the 3 traffic speeds and colors

aidan-9880, 2024-12-19:
Is there any reason to make these controllable, instead of just connected to the main 3.3v rail?

jdbaptista, 2024-12-19:
The idea is to have different color palettes for slow, medium, and fast road segments that the user can choose.

Closed 2024-12-20.

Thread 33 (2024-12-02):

Add via holes for mounting

zinkwazi, 2024-12-02:
Add 4 via holes for mounting the board on stand-offs.

jdbaptista, 2024-12-16:
Added simple edge cuts with diameter 4mm in abe4b40. I'm not sure if that is a good size for mounting holes.

zinkwazi, 2024-12-17:
Great!

Closed 2024-12-17.

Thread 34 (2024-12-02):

USB-C solder pads on rear

zinkwazi, 2024-12-02:
Add USB-C solder pads on rear so that the cable can be hidden when wall mounted.

jdbaptista, 2024-12-20:
Added power pads in commit e7b1abe, however it should be checked that this will not cause problems if connected while USB-C is connected.

jdbaptista, 2025-01-07:
After learning a little bit more about USB-C, I believe that the CC lines need to connected as well. I will continue learning about USB to say that with confidence though.

jdbaptista, 2025-01-24:
Added direct 5v connector on the back, without regard to USB, in [5147ae2](https://github.com/zinkwazi/traffic-pcb-sb/commit/5147ae25435ebc9a4acd401615e62469f92f36e0).

Closed 2025-01-24.

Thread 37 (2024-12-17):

Aesthetic changes to jumpers/test points

aidan-9880, 2024-12-17:
Thinking about changing the wire jumpers to solder jumpers and moving them to the back of the board, just to keep the front side of the board looking clean.

Also possible to do for the I2C/JTAG test points, but this might affect useability a little too much. Let me know what you think, this is a pretty easy change.

jdbaptista, 2024-12-17:
That's a good idea as those are only for development. It should be easy enough to solder across a short enough gap for the JTAG jumpers. The I2C test points will be a little annoying to work with on the back, but I don't think we will need to use them as it's already known that I2C communication is working well.

Closed 2024-12-20.

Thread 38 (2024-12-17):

Add topographical map using color printing

jdbaptista, 2024-12-17:
As we would like to use [PCBWay's color printing feature](https://www.pcbway.com/blog/News/Unlock_Color_PCB_Printing_with_PCBWay_0939d559.html), I think that adding a topographical map (contour of altitude) may look nice. Thoughts on this or other suggestions for use of the feature?

jdbaptista, 2024-12-17:
This should be helpful: https://kohacraft.com/archives/202404210835.html.

jdbaptista, 2024-12-17:
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
This is an example of what kind of map we would be able to use could look like. Its a bit difficult to even find a nice looking map, however.

jdbaptista, 2024-12-17:
note that this would be on whatever background color we choose: probably black

jdbaptista, 2024-12-18:
Determined that use of this feature does not fit the design aesthetic, which is meant to be simpler and more stylized.

Closed 2024-12-18.

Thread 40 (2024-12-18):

Some north LEDs turn off unexpectedly while sending I2C requests

jdbaptista, 2024-12-18:
This is likely due to incorrect registers in the register map, which are located in components/DotsMatrix/led_registers.h

jdbaptista, 2024-12-19:
Some blue registers are incorrect as well, which can be seen in v1_0_2ROB.

jdbaptista, 2025-03-02:
This was indeed due to incorrect register mappings, with bugs found by manual tests in the software folder and fixed shortly after.

Closed 2025-03-02.

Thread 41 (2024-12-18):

Board does not display anything if it cannot connect to wifi

jdbaptista, 2024-12-18:
This can be changed by adding a non-volatile buffer with the data last retrieved from the server.

jdbaptista, 2024-12-31:
Fixed in commit 7221253.

Closed 2024-12-31.

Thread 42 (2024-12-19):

Board does not display anything while server is updating data

jdbaptista, 2024-12-19:
This is likely due to the fact that the board writes to the file directly while querying data instead of writing to a temporary file and copying it all at once to the data file. This actually breaks both north and south directions at the same time, which is interesting because only one file is updated at a time). Here are example logs from clicking the change direction button in v1_0_2 while the server is updating data:

```
I (30710) esp-x509-crt-bundle: Certificate validated
E (31350) dot_worker: Failed to retrieve segment speeds from server
I (39170) dot_worker: Clearing North...
I (39370) dot_worker: Refreshing North...
E (39380) dot_worker: Failed to retrieve segment speeds from server
I (41510) dot_worker: Clearing South...
I (41710) dot_worker: Refreshing South...
E (41710) transport_base: poll_write select error 104, errno = Connection reset by peer, fd = 54
W (41720) transport_base: Poll timeout or error, errno=Success, fd=54, timeout_ms=5000
E (41720) HTTP_CLIENT: Error write request
E (41740) TomTom: failed to open connection
E (41750) dot_worker: Failed to retrieve segment speeds from server
```

It may be that the server cannot handle running and handling a file access at the same time? Although this seems to be disproven by accessing bearanvil.com while running the script.

jdbaptista, 2024-12-31:
The break is due to esp_http_client_cleanup() not being called after the server responds with a non-200 code. This was fixed as of 7221253.

jdbaptista, 2024-12-31:
I'm not exactly sure what the issue here was or why it was actually an issue, but as of 1a20074, if any request to the server fails, data stored in non-volatile storage from the most recent request is used and the error LED is flashed. I'm closing this unless it proves to be a bigger issue that affects functionality.

Closed 2024-12-31.

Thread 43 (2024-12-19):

Add an LED to indicate that an OTA update is available

jdbaptista, 2024-12-19:
This will avoid me having to manually tell users (Greg) that an update is available. Alternatively we could implement forced auto updating, which may be better but not the best option for security purposes.

aidan-9880, 2024-12-19:
Just fyi we're running out of IO pins. I think this would take up the last one, assuming we keep the photoresistor.

jdbaptista, 2024-12-19:
If we have space, we should implement this as an LED in one of the matrices (could be a white LED), as well as the color key LEDs

aidan-9880, 2024-12-19:
Good idea, definitely doable. Will do this for #32 as well.

Closed 2024-12-20.

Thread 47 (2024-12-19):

Pair up directional LED indicators to save on IO pins

aidan-9880, 2024-12-19:
As referenced in https://github.com/zinkwazi/traffic-pcb-sb/issues/43#issuecomment-2555755112_ we're basically out of IO pins. If we're fine with losing individual control of the compass rose LEDs (i.e. only south/east or north/west on at a time) we could just connect them in pairs to the same pin and easily open up 2 IO pins.

aidan-9880, 2024-12-19:
Don't think this is necessary anymore, but it's good to keep in mind if we need more IO in the future.

Closed 2024-12-19.

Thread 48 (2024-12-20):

remove api key from server script

jdbaptista, 2024-12-20:
It is quite easy to accidentally commit this to the repo (whoops)

jdbaptista, 2024-12-20:
No keys are currently leaked, a previous leaked key has been rotated.

jdbaptista, 2025-03-02:
This was completed.

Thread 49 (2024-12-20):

Base LEDs off percentage from free flow instead of absolute speed

jdbaptista, 2024-12-20:

jdbaptista, 2024-12-31:
Fixed in 7221253.

Closed 2024-12-31.

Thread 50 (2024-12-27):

latitude and longitude are inverted in led locations and probably more

jdbaptista, 2024-12-27:

Closed 2025-04-23.

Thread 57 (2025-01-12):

LED matrix 2 turns off during reset on V1_0 of the hardware.

jdbaptista, 2025-01-12:
Not sure why this is happening, but I'm sure a change of which pin it is connected to will change the behavior.

jdbaptista, 2025-01-28:
Should be fixed in V2_0. Removed SBD lines, which were likely shutting down the second matrix during an esp32 reset.

Closed 2025-01-28.

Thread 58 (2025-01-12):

Scripts do not take into account road closures

jdbaptista, 2025-01-12:
In light of the Palisades fire, the road there is closed. The freeFlowSpeed for a corresponding segment is currently 11mph, which does not reflect the usual free flow speed. The 'roadClosure' attribute states TRUE, which should be reflected in the device in some way; if strobing red will indicate slow, then perhaps flashing red can indicate a closure.

jdbaptista, 2025-02-13:
Fixed in commit cb83b07.

Closed 2025-02-13.

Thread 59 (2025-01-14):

Device cannot connect to wifi networks with particular names.

jdbaptista, 2025-01-14:
It cannot connect to a network named "Jaden's IPhone", however it can connect to a network named "JadenIPhone".

jdbaptista, 2025-01-14:
It may be that my phone hotspot simply doesn't like to connect very much.

jdbaptista, 2025-04-23:
This is an issue arising from the fact that UTF-8 encoding includes multiple very similar marks for quotations and quotes. My computer keyboard can't write the correct quote necessary, nor can it be pasted into the esp-idf monitor. I've considered adding a feature to directly write UTF-8 bytes using a special character and adding an escape character, but I think this will be a waste of time considering the board will have a captive portal before it's final release. The captive portal will hopefully be able to list available networks, or at least handle this in a smarter way (no one wants to be writing UTF-8 bytes directly). I will change the title to note that this is more of a feature addition than a bug.

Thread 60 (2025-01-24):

Copper!

jdbaptista, 2025-01-24:
Change road number symbols from silkscreen layer to layer 1 and expose copper by making footprints. This should also be added for the islands and potentially the Outside Open logo.

jdbaptista, 2025-01-28:
Added in commit f730deb.

Closed 2025-01-28.

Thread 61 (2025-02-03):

Message format from server to device improvements.

jdbaptista, 2025-02-03:
The current message format makes many assumptions in order to minimize the overhead of unpacking server data, in terms of both compute time and importantly code size. Segment speed data is currently stored directly as a binary array, where the indices of the array correspond to LED numbers. When there is only one version of hardware for the server to curate data for, the assumptions below are always true, which is not necessarily the case when there are multiple board versions:
1. LED numbers always correspond to the same road segment.
2. LED numbers that correspond to road segments are sequential (minimizes unnecessary zeros).
3. LED numbers that correspond to a road segment in one board are not used for special purposes on another (ex. LED number 0 can be considered a special purpose LED).

When designing V2_0, special care has been taken to make sure that assumptions 1 and 2 are obeyed, however assumption 3 is not obeyed because there are now indicator LEDs within the middle of the array of LEDs. Board firmware can deal with this problem by creating version specific code, however this is error prone, with changes to the codebase targeting one version potentially breaking another. The server may be able to deal with this issue by keeping different files for different versions of boards, however this increases server overhead as it needs to keep multiple copies of the same data. This isn't a large issue, but it is also error-prone to rely on the assumptions above and to keep track of which versions of the board violate a particular assumption, which versions of the board require which road segment data, etc.

A new message format should be designed that achieves the following:
1. Overhead should be kept reasonably low, with code size being more important than compute time for this application (this is to allow use of 4MB versions of ESP32s instead of more expensive 8MB versions).
2. LED mappings should be made explicit with devices able to verify that the speed supplied by the server corresponds to the LED they expect it to, which will also allow different versions of the board to make adjustments if necessary (whereas currently the server is making adjustments).
3. Server response times should be quick, ie. responses should ideally be simple fetches of small files without additional requests.
4. The format should be extensible and not require previous board versions to update firmware in order to support a new board version.
5. The format should minimize the amount of duplicate data stored on the server for different versions of boards and firmware when possible.
6. The format should minimize the complexity of server code to reduce errors.

jdbaptista, 2025-02-03:
To satisfy goal 3, I will design a format where each version of the board requests data from the same file. This reduces the amount of duplicate information on the server. As this means that the size of the file is unbounded with the amount of versions, further versions can simply request data from a different file if the current file is too large.

Assumption 2 can be removed by simply adding explicit LED numbers to each segment speed. Assumption 1 can be removed by adding blocks of override mappings of the base V1_0 mapping. Example:

{ "V2_0_1",
  block_length,
  [{LED_N1, speed},
   {LED_N2, speed}
  ],
 register_verify_num
}

Multiple blocks can be added for different board versions. This also takes care of assumption 3 because it allows particular versions to zero out LEDs that do not correspond to road segments that do on previous versions of the board.

Using a block_length allows boards to jump past blocks that are not theirs, boards can simply ignore data that they don't need, with jumping able to be implemented in a small amount of extra code. This does increase runtime, however this should not be an issue, especially if the server starts fresh with a new file if real-time constraints become apparent.

The goal of the message is ultimately to update the color of each LED on the board corresponding to the speed of the corresponding road segment. This means that verification should be verifying that the board updated the correct LED matrix registers using the proper road segment speed provided by the server. If data transfer fails to do this in some way, likely due to a programming error in decoding the message format or server mapping error, then the matrix registers will change incorrectly. A way to verify that the correct registers are changed without directly mapping registers in the message format is to add some checksum or verification string to the end of each board version's block. This verification number should be unique (or improbably non-unique) when the board updates all of the LEDs correctly. The board should not be able to create the verification number if even one LED was updated incorrectly.

Example: Suppose there are two hardware versions with LED_N1 and LED_N2 switched, ie. N1 on V1 corresponds to the same segment as N2 on V2 and vice-versa. In this case, if V1 uses V2's block to override N1 and N2 incorrectly, then V1 should generate a register verification number using its built-in register mappings that is not the same as the register_verify_num provided by the server. In this case, it knows something has gone wrong and does not update the LEDs.

A probable issue with implementing a verification method in this way is that boards use different registers for different LED numbers. It is not feasible for this to not be the case for a new board, as was clear in developing V2_0. That said, it is highly likely that there are verification methods that reduce the probability of generating a correct verification number with incorrect data to near zero even if registers are scrambled.

jdbaptista, 2025-02-04:
The register_verify_num can simply be an HMAC of the segment speeds that the server expects the device to retrieve, where the HMAC key is specific to the board version. In this way, two different board versions will generate different HMACs of the retrieved data if they both retrieve the same array. The one that has retrieved the array incorrectly will have a different HMAC than the one sent by the server.

What can go wrong with this method? When a new version of the board is created, the creator needs to be sure that LED numbers are not changed from previous versions of the board (to reduce version specific addendums to the file). They also need to be sure to update the server script to generate an addendum that adds new LEDs or fixes LED numbers that have changed. In doing this, they may accidentally mess up the mapping of segment to LED number to another version of the board. This can be checked at compile-time with unit testing, but it is probably a smart idea to add some run-time mechanism to allow devices to independently check that the server is producing the correct output for their hardware.

The key used for board versions can be generated by hashing the particular mapping of LED numbers to segment openLR codes (or segment number). In this way, the server can generate a key based on the openLR codes it used for a board version. As long as the programmer is careful to give the board version the proper key corresponding to the mappings it expects, the board can verify that both the mappings and segments speeds are what the server means to be sending (ie. device interpretation of the file is correct).

jdbaptista, 2025-02-06:
I'm worried that this format may, if there are many board versions, not be suitable if the amount of available memory on the devices is low. What might happen is that one poorly optimized version of the device uses a lot of memory and does not have much available for storing the result of a request. If a new, optimized version of the device has space for an addendum, but the first device does not, then a new file must be written duplicating all of the data for the new device, and the first file must still be kept around for backwards compatibility.

While it is not as clean as having a single file on the server, having a file structure of: folder[filename.txt, filename_addendums[v2.add,...]] solves the issue above and may make things more readable if the underlying file format is human readable. This is getting slightly abstract, but this should work well for this project.

jdbaptista, 2025-02-25:
V1_0 uses V1_0_5 csv files as of 4876f751797920e78e574d6305a5128d0c05b4b3. This is not yet a full release, however.

jdbaptista, 2025-02-28:
Added a full addendum system in edf8eba1dbc0ec98fb4bc835e5363b152014ee5d.

Closed 2025-02-28.

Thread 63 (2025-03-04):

LED 294 RED/GREEN register mappings are incorrect on V1_0.

jdbaptista, 2025-03-04:
This has been a problem since before moving mappings from header files to source files. I verified this is an issue using the manual LED mapping test,
whose output is:

```
I (392) test: LED 294 RED  , 0x8F
I (392) verifier: Verify LED...
I (11022) test: LED 294 GREEN, 0x8E
I (11022) verifier: Verify LED...
I (13542) test: LED 294 BLUE , 0x8D
I (13542) verifier: Verify LED...
```

I'm quite confused because nothing has changed and I thought that it was fine before. Oh well, guess I'll have to go over the mappings again :(.

jdbaptista, 2025-04-14:
I have double checked the registers and they are correct. I almost think that this is a hardware issue local to my development board. Odd bug.

Closed 2025-04-23.

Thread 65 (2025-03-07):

Refresh in non-wifi environment only updates part of the board

jdbaptista, 2025-03-07:
This is likely due to the addition of the addendum system, but really could be anything.

jdbaptista, 2025-03-19:
I believe this is fixed as of 422599a8bbf20c1490c4b813727a881d258d88fb.

Closed 2025-03-19.

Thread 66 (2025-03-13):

V2_0 LED 288 red register mapping is incorrect

jdbaptista, 2025-03-13:
It is mapped to 0x31, however no LED lights up on the board when tested.

jdbaptista, 2025-03-15:
Fixed in 870ace4200f67632214768a9efd2a1e2b77aafd3.

Closed 2025-03-15.

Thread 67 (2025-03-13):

V2_0 R139 is 20 ohms instead of 2k ohms

jdbaptista, 2025-03-13:
This is a pullup or an I2C line, so it must be changed.

jdbaptista, 2025-03-15:
Fixed in 923cbbc2a25e32602913858071b1a7146bdbb684, alongside a few other incorrect values (but surprisingly working). There is no functional issues with the other resistors, however they consume more power than necessary.

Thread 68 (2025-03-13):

V2_0 'Heavy' label is cutoff by via

jdbaptista, 2025-03-13:
The silkscreen 'H' is slightly blocked by a via, which must be moved.

jdbaptista, 2025-04-23:
Fixed in commit 1ed808975c5e80051ed732f3718a3bb9f7dd6072.

Closed 2025-04-23.

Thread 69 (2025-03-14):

Device does not request typical data upon wifi connection

jdbaptista, 2025-03-14:
This will not occur after the device fails to request typical data initially, then achieves a good wifi connection later. It seems that the retrieval from nvs is also broken? More testing is required to double check this.

jdbaptista, 2025-04-14:
This is no longer an issue as of v0.6.0.

Closed 2025-04-14.

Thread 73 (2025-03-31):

Remove dependencies on errno

jdbaptista, 2025-03-31:
`errno` is not thread safe in FreeRTOS, so functions using it to return error codes must be replaced or proven to fail safely in the codebase. In the worst case scenario, the OTA task overwrites errno, which the main task would see instead of an error code.

jdbaptista, 2025-04-15:
I don't think that errno is currently used for error handling, so I will close this and fix it in the codebase if I come across it.

Closed 2025-04-15.

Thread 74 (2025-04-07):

Colors sometimes are incorrect

jdbaptista, 2025-04-07:
This arises in in-development v0.6.0, where the strobe task changes the matrix page state in between the main task accessing it. This can cause the main task to change the incorrect matrix registers, and vice-versa with the strobe task changing incorrect registers, leading to incorrect LED colors. Quite an interesting bug, which can be fixed by guarding matrix page states with mutexes.

jdbaptista, 2025-04-09:
Should be fixed in commit 4073b6adf9d4e4cdf24d4ef38d579624af70d548. If not, it at least is very very less frequent.

Closed 2025-04-09.

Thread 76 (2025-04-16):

Loading animation occurs through direction LED flashing

jdbaptista, 2025-04-16:
This looks alright, a bit wacky, but it shouldn't be this way and should be fixed.

jdbaptista, 2025-04-23:
Fixed in commit b011b83.

Closed 2025-04-23.

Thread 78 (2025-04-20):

Error LED should stop flashing when wifi connects

jdbaptista, 2025-04-20:
In other words, the device should perform a data action when this happens.

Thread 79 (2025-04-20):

Configuration menu is overrun by strobe logging

jdbaptista, 2025-04-20:
```
Wifi SSID: I (2537) strobe_task: Registering LED 412
I (2537) strobe_task: Registering LED 409
I (2537) strobe_task: Registering LED 410
```

jdbaptista, 2025-04-23:
Fixed in commit b011b83.

Closed 2025-04-23.

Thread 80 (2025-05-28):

Boards should identify themselves to the server.

jdbaptista, 2025-05-28:
Unique IDs can be issued by the server on request, which can then be used for telemetry.

jdbaptista, 2025-06-01:
Added in 51e330e1f0078f1119988056d6486a15c4f2bdc3.

Closed 2025-06-01.

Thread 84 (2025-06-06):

Failure to connect to server & stuck loading animation

jdbaptista, 2025-06-06:
Hardware Version: V2_0
Firmware Version: v0.8.3ARYB05

The board was powered for a long time and at a certain point the error LED was flashing while the wifi LED was on. To confirm issues, the OTA button was pressed, after which the OTA LED turned white for some time, then red. It was assumed to be a memory leak, so a reset was initiated, after which the loading animation was stuck. When moved to a location away from the wifi network the board was configured to connect to, the loading animation was not stuck. Instead, the board logged:

```
E (5741) esp-tls: couldn't get hostname for :bearanvil.com: getaddrinfo() returns 202, addrinfo=0x0
E (5741) esp-tls: Failed to open new connection
E (5751) transport_base: Failed to open a new connection
E (5751) HTTP_CLIENT: Connection failed, sock < 0
```
After, the board displayed previously collected traffic data as normal. That is, there are potentially two undiscovered bugs.

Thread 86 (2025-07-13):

LED Mappings are Incorrect

jdbaptista, 2025-07-13:
Most incorrect tile mappings are not causing issues because segment data is used if it fails. If the segment data also fails, then the LED speed will be -1 and the board will not show any value for the road segment. I suspect that TomTom periodically changes how their servers choose data to present, in which case this will be a recurring issue that will need to be fixed. However, it may be something else.

```
Broken LED mappings:

SOUTHBOUND:
V2_0_0 Addendum:
[395, 396, 397]: tile 22/718656/1668843
[384, 385]: tile 22/716452/1670434

Regular:
[218]: tile 22/720153/1678063

[179]: tile 22/716772/1673995
[179]: Segment C6u++hhCSQEPKAJK+CgBAA== is not the expected code: C6u+/RhCeQEQHQGb+k4BERAAxPzHAR8=

NORTHBOUND:
V2_0_0 Addendum:
[384, 385]: tile 22/716454/1670431

Regular:
[315]: C6wiOhhFBQEWLvTnAo0BCA== is not the expected code: C6wiQBhFBgEWL/TaAooBCA==
[281]: tile 22/721078/1673345
```

jdbaptista, 2025-07-13:
The southbound 179 tile has definitely changed and, unfortunately, I can't seem to find a new coordinate. The points return either nothing or both north and southbound, which cannot currently be parsed. The point will be unchanged and the segment code will be updated to the new code, which is the same road.  The tile is now NULL to indicate it is intentional.

Southbound 218 updated to 33.822181,-118.196994,22/720057/1677988, which is the same segment code as previously. This is actually unchanged in the repo input CSV, surprisingly.

Northbound 315 OpenLR code is incorrect, so a new point is chosen: `34.134385, -117.957328,NULL,C6wgohhFTgEZNvLyAdsBCA==,76,` which contains a new typical speed of 76 instead of 70.

 The northbound 281 tile is experiencing the same issue as southbound 179, where the northbound and southbound road segments are now being presented at the same time. The tile will be NULL.

Northbound and southbound [384, 385] tiles are experiencing the same issue as southbound 179, where the northbound and southbound road segments are now being presented at the same times. The tile will be NULL.

Southbound [395, 396, 397] tiles are experiencing the same issue as southbound 179. The tile will be NULL.

With these changes, the logs don't show any obvious issues.

jdbaptista, 2025-07-16:
Northbound [384, 385] has switched again as well, to: C6u6uxhr0gohNgHKCqMKEg== from C6u6uxhr0gohNgHXCroKEg==. I will be watching this more closely for a little while. This may be a different issue than I expect, I'm not sure now.

jdbaptista, 2025-07-16:
281 also has this issue. previously C6wEmRhJUAEYKPYQ/9ABBw==, now C6wEmRhJUAEYJ/ZH/9UBBw==.

Closed 2025-07-13.

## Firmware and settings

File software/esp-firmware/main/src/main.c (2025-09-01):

/**
 * main.c
 * 
 * This file contains the entrypoint task
 * for the application (app_main) and
 * configuration including function hooks.
 */

#include <limits.h>
#include <stdbool.h>
#include <stddef.h>
#include <stdint.h>

#include "esp_mac.h"
#include "esp_err.h"
#include "esp_log.h"
#include "esp_timer.h"
#include "freertos/FreeRTOS.h"
#include "freertos/projdefs.h"
#include "freertos/task.h"
#include "sdkconfig.h"

#include "animations.h"
#include "api_connect.h"
#include "app_err.h"
#include "app_errors.h"
#include "led_registers.h"
#include "indicators.h"
#include "input.h"
#include "input_queue.h"
#include "main_types.h"
#include "refresh.h"
#include "routines.h"
#include "utilities.h"

#include "initialize.h"

#define TAG "app_main"

#define NOT_QUICK     (false)

static Direction currDir = SOUTH; // the currently displayed traffic direction

static esp_err_t mainRefresh(bool toggleDirection);

/**
 * @brief The entrypoint task of the application.
 * 
 * Initializes other tasks, requests user settings, then handles button presses
 * for LED refreshes. As this task handles user input, it should not do a lot
 * of processing. Rather, heavy processing is primarily left to vDotWorkerTask.
 */
void app_main(void)
{
    MainCommand cmd;
    bool toggleDirection = false;
    bool prevCmdAborted = false;
    esp_err_t err;
    uint8_t mac[6];

    /* set task priority */
    vTaskPrioritySet(NULL, CONFIG_MAIN_PRIO);

    /* print firmware information */
    err = initializeLogChannel();
    if (err != ESP_OK) throwFatalError();
    ESP_LOGE(TAG, "Hardware Version: " HARDWARE_VERSION_STR);
    ESP_LOGE(TAG, "Firmware Version: " FIRMWARE_VERSION_STR);
    ESP_LOGE(TAG, "OTA Binary: " FIRMWARE_UPGRADE_URL);
    err = esp_base_mac_addr_get(mac);
    if (err != ESP_OK) throwFatalError();
    ESP_LOGE(TAG, "Base MAC Address: %.2x:%.2x:%.2x:%.2x:%.2x:%.2x", mac[0], mac[1], mac[2], mac[3], mac[4], mac[5]);

    /* initialize application */
    err = initializeApplication();
    if (err != ESP_OK) throwFatalError(); // if app_errors component uninitialized, this still traps
    err = enableHoldDirButton();
    if (err != ESP_OK) throwFatalError();
    err = enableQuickDirButton();
    if (err != ESP_OK) throwFatalError();
    err = enableOTAButton();
    if (err != ESP_OK) throwFatalError();

    /* TODO: check nighttime mode status */

    /* initial refresh */
    cmd = MAIN_CMD_QUICK_DIR_BTN;
    (void) quickClearBoard(currDir); // TODO: handle I2C errors
    err = mainRefresh(toggleDirection);
    if (REFRESH_ABORT == err) {
      quickClearBoard(currDir);
      prevCmdAborted = true;
    }
    
    /* handle commands from various sources */
    while (true) {
      /* wait for next command */
      if (pdFALSE == xQueueReceive(inputQueue, &cmd, pdMS_TO_TICKS(CONFIG_LED_REFRESH_PERIOD * 60 * 1000)))
      {
        /* no received input, timeout occurred */
        cmd = MAIN_CMD_TIMEOUT;
      }

      /* handle current command */
      toggleDirection = false;
      switch (cmd)
      {
        case MAIN_CMD_QUICK_DIR_BTN:
          ESP_LOGI(TAG, "quick");
          toggleDirection = true;
          /* falls through */
        case MAIN_CMD_TIMEOUT:
          ESP_LOGI(TAG, "refresh");
          err = decrementAbortCount(); // keep refresh abort counter synchronized with queue items
          if (ESP_OK != err)
          {
            ESP_LOGE(TAG, "could not decrement abort counter");
            throwFatalError();
          }
          if (!abortCountZero()) continue;
          if (!prevCmdAborted) {
            err = clearBoard(currDir, NOT_QUICK);
            if (REFRESH_ABORT == err) {
              quickClearBoard(currDir);
              prevCmdAborted = true;
              continue;
            }
          }
          err = mainRefresh(toggleDirection);
          if (REFRESH_ABORT == err) {
            quickClearBoard(currDir);
            prevCmdAborted = true;
            continue;
          }
          if (ESP_OK != err) throwFatalError();
          break;
        case MAIN_CMD_HOLD_DIR_BTN:
          ESP_LOGI(TAG, "long");
          /* TODO: toggle nighttime mode enabled */
          break;
        case MAIN_CMD_SCHEDULED:
          ESP_LOGI(TAG, "scheduled");
          /* TODO: nighttime mode activation/deactivation */
          break;
        default:
          ESP_LOGE(TAG, "received unknown main command: %d", cmd);
          throwFatalError(); // should not be possible
      }

      prevCmdAborted = false;
    }

    /* emergency handling */
    ESP_LOGE(TAG, "Main task is exiting!");
    throwFatalError();
}

/**
 * @brief Handles everything that needs to happen after a toggle button press.
 * 
 * @param[in] toggleDirection Whether to toggle the current direction or not.
 * @param[in] typicalNoth An array filled with typical north road segment speeds.
 * @param[in] typicalSouth An array filled with typical south road segment speeds.
 * 
 * @returns ESP_OK if successful.
 * REFRESH_ABORT if a new command is available on the main queue.
 */
static esp_err_t mainRefresh(bool toggleDirection) {
  esp_err_t err;

  /* handle toggle button press */
  if (toggleDirection && NORTH == currDir) {
    currDir = SOUTH;
  } else if (toggleDirection && SOUTH == currDir) {
    currDir = NORTH;
  }

  /* refresh LEDs */
  err = indicateDirection(currDir);
  if (err != ESP_OK) return err;
  switch (currDir)
  {
    case NORTH:
      err = refreshBoard(NORTH, CURVED_LINE_NORTH);
      break;
    case SOUTH:
      err = refreshBoard(SOUTH, CURVED_LINE_SOUTH);
      break;
    default: 
      THROW_ERR(ESP_FAIL);
  }
  return err;
}

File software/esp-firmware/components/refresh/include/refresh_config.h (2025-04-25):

/**
 * refresh_config.h
 * 
 * Contains macro configuration options for refresh.c, with the option to
 * use extern variables instead of macros by defining CONFIG_EXTERN_REFRESH_CONFIG.
 * This replacement is useful for testing with different values of configuration
 * macros while maintaining the benefits of static configuration options.
 */

#include "esp_http_client.h"
#include "sdkconfig.h"

/**
 * Default definitions of macros, which add a layer of indirection allowing
 * extern macro replacements to be set to the value that the macro would be.
 */

#define DEF_URL_DATA_FILE_TYPE ".csv"

#define DEF_URL_DATA_CURRENT_NORTH CONFIG_DATA_SERVER "/current_data/data_north_" SERVER_VERSION_STR URL_DATA_FILE_TYPE
#define DEF_URL_DATA_CURRENT_SOUTH CONFIG_DATA_SERVER "/current_data/data_south_" SERVER_VERSION_STR URL_DATA_FILE_TYPE
#define DEF_URL_DATA_TYPICAL_NORTH CONFIG_DATA_SERVER "/current_data/typical_north_" SERVER_VERSION_STR URL_DATA_FILE_TYPE
#define DEF_URL_DATA_TYPICAL_SOUTH CONFIG_DATA_SERVER "/current_data/typical_south_" SERVER_VERSION_STR URL_DATA_FILE_TYPE

#define DEF_API_METHOD HTTP_METHOD_GET
#define DEF_API_AUTH_TYPE HTTP_AUTH_TYPE_NONE

#define DEF_API_RETRY_CONN_NUM 5

#define DEF_MATRIX_RETRY_NUM 15

#define DEF_DEFAULT_SCALE (0xFF)

#ifdef CONFIG_SUPPORT_STROBING
#define DEF_STROBE_LOW_SCALE (0x20)
#define DEF_STROBE_STEP_HIGH (10)
#define DEF_STROBE_STEP_LOW (10)
#endif /* CONFIG_SUPPORT_STROBING */

#ifndef CONFIG_EXTERN_REFRESH_CONFIG

/**
 * Macro configuration options, set by the default macros above.
 */

#define URL_DATA_FILE_TYPE DEF_URL_DATA_FILE_TYPE

#define URL_DATA_CURRENT_NORTH DEF_URL_DATA_CURRENT_NORTH
#define URL_DATA_CURRENT_SOUTH DEF_URL_DATA_CURRENT_SOUTH
#define URL_DATA_TYPICAL_NORTH DEF_URL_DATA_TYPICAL_NORTH
#define URL_DATA_TYPICAL_SOUTH DEF_URL_DATA_TYPICAL_SOUTH

/* TomTom HTTPS configuration */
#define API_METHOD DEF_API_METHOD
#define API_AUTH_TYPE DEF_API_AUTH_TYPE

#define API_RETRY_CONN_NUM DEF_API_RETRY_CONN_NUM

#define MATRIX_RETRY_NUM DEF_MATRIX_RETRY_NUM

#define DEFAULT_SCALE DEF_DEFAULT_SCALE

#ifdef CONFIG_SUPPORT_STROBING
#define STROBE_LOW_SCALE DEF_STROBE_LOW_SCALE
#define STROBE_STEP_HIGH DEF_STROBE_STEP_HIGH
#define STROBE_STEP_LOW DEF_STROBE_STEP_LOW
#endif /* CONFIG_SUPPORT_STROBING */

#else /* CONFIG_EXTERN_REFRESH_CONFIG */

/**
 * Extern definitions of configuration options, which replace macros to allow
 * testing with multiple values of macros.
 */

#include <stdint.h>

extern const char *URL_DATA_FILE_TYPE;

extern const char *URL_DATA_CURRENT_NORTH;
extern const char *URL_DATA_CURRENT_SOUTH;
extern const char *URL_DATA_TYPICAL_NORTH;
extern const char *URL_DATA_TYPICAL_SOUTH;

/* TomTom HTTPS configuration */
extern esp_http_client_method_t API_METHOD;
extern esp_http_client_auth_type_t API_AUTH_TYPE;

extern uint32_t API_RETRY_CONN_NUM;

extern uint32_t MATRIX_RETRY_NUM;

extern uint8_t DEFAULT_SCALE;

#ifdef CONFIG_SUPPORT_STROBING
extern uint8_t STROBE_LOW_SCALE;
extern uint8_t STROBE_STEP_HIGH;
extern uint8_t STROBE_STEP_LOW;
#endif /* CONFIG_SUPPORT_STROBING */

void macroResetRefreshConfig(void);

#endif /* CONFIG_EXTERN_REFRESH_CONFIG */

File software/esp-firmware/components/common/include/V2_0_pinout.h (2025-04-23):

/**
 * pinout.h
 * 
 * This file holds definitions for which ports and pins 
 * various data lines connect to on the PCB for V1_0.
 */

#ifndef V_PINOUT_H_
#define V_PINOUT_H_

#include "sdkconfig.h"

#if CONFIG_HARDWARE_VERSION == 2

#include "driver/gpio.h"

/* Status Indicators */
#define WIFI_LED_NUM     (414)
#define ERROR_LED_NUM    (413)
#define OTA_LED_NUM      (325)

/* LED Color Legend */
#define HEAVY_LED_NUM    (327)
#define MEDIUM_LED_NUM   (326)
#define LIGHT_LED_NUM    (328)

/* Settings Button */
#define IO_SW_PIN        GPIO_NUM_0 // Strapping pin, needs pullup

/* Direction Indicator */
#define T_SW_PIN         GPIO_NUM_48
#define NORTH_LED_NUM    (411)
#define SOUTH_LED_NUM    (409)
#define EAST_LED_NUM     (412)
#define WEST_LED_NUM     (410)

/* LED Matrix Pins */
#define INT1_PIN         GPIO_NUM_17
#define INT2_PIN         GPIO_NUM_15
#define INT3_PIN         GPIO_NUM_6
#define INT4_PIN         GPIO_NUM_11

/* I2C Pins */
#define I2C1_PORT        (-1) // auto-select available I2C port
#define SCL1_PIN         GPIO_NUM_9
#define SDA1_PIN         GPIO_NUM_10
#define I2C2_PORT        (-1) // auto-select available I2C port
#define SCL2_PIN         GPIO_NUM_18
#define SDA2_PIN         GPIO_NUM_8

/* Photoresistor pin */
#define PHOTO_PIN        GPIO_NUM_4
#define PHOTO_ADC_CHAN   (3)

/* USB Pins */
#define USB_MINUS        GPIO_NUM_19
#define USB_PLUS         GPIO_NUM_20

#endif /* CONFIG_HARDWARE_VERSION == 1 */
#endif /* V_PINOUT_H_ */

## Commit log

2024-08-30 Update KiCAD files
    [BOM-traffic_paradise.csv, BOM-v0.csv, matrix_1.kicad_sch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]
2024-08-30 Update KiCAD files
    correct files this time :)
    [matrix_1.kicad_sch, matrix_2.kicad_sch, matrix_3.kicad_sch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]
2024-08-31 move sbd/int lines off of input only gpio pins
    [traffic_paradise.kicad_sch]
2024-09-02 move various esp32 pins to avoid strapping pins
    [traffic_paradise.kicad_sch]
2024-09-03 Few changes
    Added a missing power trace and removed C10 from assembly (can occasionally cause problems on resetting)
    [traffic_paradise.kicad_sch]
2024-09-03 Fixed missing I2C connections
2024-09-03 Re-exported manufacturing files
    [BOM-traffic_paradise.csv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]
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2024-09-04 add I2C test points
    [traffic_paradise.kicad_sch]
2024-09-08 migrate to esp-idf v5.3.1 (new i2c api) & define pins
2024-09-17 map fwy 101 and lower I-5
    [led_locations.xlsx]
2024-09-17 map CA-1
    [led_locations.xlsx]
2024-09-18 map CA-118
    [led_locations.xlsx]
2024-09-18 map I-210
    [led_locations.xlsx]
2024-09-18 map upper I-5 and I-10
    [led_locations.xlsx]
2024-09-20 map I-405
    [led_locations.xlsx]
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2024-10-11 fix and sort led locations
    [led_locations.xlsx]
2024-10-11 Revert "fix and sort led locations"
    This reverts commit e756b29f016c12b438b9199db3c82ae27c84d8e2.
    [led_locations.xlsx]
2024-10-11 fix led locations and add to source code
    [led_locations.xlsx]
2024-10-27 Fix I2C matrix issues
    [main.c]
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2024-10-30 fix south led location issues
    [led_locations.xlsx]
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2024-10-30 remove NB CA-118 duplicate LED 142
    [led_locations.xlsx]
2024-10-30 fix SB LED 4 and small changes
    [led_locations.xlsx]
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2024-11-05 add error led indication of tomtom error
    [main.c]
2024-11-05 add error led synchronization
    [main.c]
2024-11-05 fix uart lines
    [traffic_paradise.kicad_sch]
2024-11-13 make i2c error handling more robust
    [main.c]
2024-11-18 Revert "use single certificate authority"
    This reverts commit 377bb9baf00206b261f3fa41f6a6cc91d81e9833.
    [main.c]
2024-11-18 move led_east to non-strapping pin
    [traffic_paradise.kicad_sch]
2024-11-19 reduce brightness of white indicator leds
    [BOM-traffic_paradise.csv, traffic_paradise.kicad_sch]
2024-11-21 add jtag functionality with tristate buffers
    [BOM-traffic_paradise.csv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]
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2024-12-09 refactor leds 329/330 and small fixes
    [led_locations.xlsx]
2024-12-09 create main server python script
    [led_locations.csv]
2024-12-12 fix duplicate led reference: south 26
    [led_locations.csv, led_locations.xlsx]
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2024-12-17 changed test points/jumpers, some other changes
    also added photoresistor connected to pin 4 (ADC1) and slightly changed some silkscreen
    [traffic_paradise.kicad_sch]
2024-12-17 V1_0_1 minor fixes and changes
    [main.c, worker.c]
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2024-12-19 Added LED key, update LED, some other changes
    [matrix_3.kicad_sch, traffic_paradise.kicad_sch]
2024-12-20 Modified silkscreen, generated production files
    [BOM-traffic_paradise.csv, matrix_3.kicad_sch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]
2024-12-20 clean up server script
    [led_locations.csv, led_locations.xlsx]
2024-12-20 add leds to 126 segment
    [matrix_3.kicad_sch]
2024-12-20 add power wall mount
    [traffic_paradise.kicad_sch]
2024-12-27 create example server script that uses tile flow API endpoint
    [new_led_locations.csv]
2024-12-31 fix bug when server request is not 200
    [tasks.c]
2024-12-31 add error handling state machine
    [main.c, routines.c, utilities.c]
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2024-12-31 fix data URL source
    [tasks.c]
2025-01-08 add and route matrix 4
    [matrix_1.kicad_sch, matrix_2.kicad_sch, matrix_3.kicad_sch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]
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2025-01-09 route matrices 1,2,4
    [matrix_4.kicad_sch]
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2025-01-10 update matrix 4 i2c address
    [matrix_4.kicad_sch]
2025-01-11 esp32c3 upgrade, route usb, fix errors
    [matrix_2.kicad_sch, matrix_3.kicad_sch, matrix_4.kicad_sch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]
2025-01-13 Minor changes
    Moved LED driver pins around and optimized board layout
    [matrix_1.kicad_sch, traffic_paradise.kicad_sch]
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2025-01-14 move register test and fix found bugs
    [main.c]
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2025-01-14 fix bugs during no wifi
    [main.c, tasks.c, utilities.c]
2025-01-15 fix error caused by attempt to remove non-existent nvs entry
    [tasks.c, utilities.c]
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2025-01-21 improve led_matrix error handling & documentation
2025-01-21 add reverse current protection on wall mount & generate BOM
    [BOM-traffic_paradise.csv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]
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2025-01-22 create production files, missing schottky diode
    [BOM-traffic_paradise.csv, BOM_traffic_paradise.xlsx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]
2025-01-22 reexport production files, missing schottky diode
    [traffic_paradise-B_Cu.gbr, traffic_paradise-B_Mask.gbr, traffic_paradise-B_Paste.gbr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]
2025-01-24 add schottky diodes and generate prod files
    [BOM-traffic_paradise.csv, BOM_traffic_paradise.xlsx, DIO_RB051MM_ROM.step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]
2025-01-24 add exposed copper sections
    [traffic_paradise.kicad_sch]
2025-01-24 remove sbd lines & fix drc errors & export prod files
    [matrix_1.kicad_sch, matrix_2.kicad_sch, matrix_3.kicad_sch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]
2025-01-27 add new led mappings for tile endpoint
    [led_locations.csv, new_led_locations.csv]
2025-01-27 small aesthetic changes & export V2_0
    [CPL-traffic_paradise.csv, traffic_paradise-B_Cu.gbr, traffic_paradise-B_Mask.gbr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]
2025-01-28 jlcpcb prod and alternate part choices
    [BOM-traffic_paradise.csv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]
2025-01-28 part changes to match footprints
    [BOM-traffic_paradise.csv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]
2025-01-28 fix pcbway files
    [BOM-traffic_paradise.csv, BOM_traffic_paradise.xlsx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]
2025-01-28 add website label
    [traffic_paradise-B_Cu.gbr, traffic_paradise-B_Mask.gbr, traffic_paradise-B_Paste.gbr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]
2025-01-31 update new led numbers
    [matrix_1.kicad_sch, matrix_2.kicad_sch, matrix_3.kicad_sch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]
2025-01-31 fix small soldermask bridges and update production files
    [BOM-traffic_paradise.csv, BOM_traffic_paradise.xlsx, OO_TrafficPCB_V2_0_BOM_jlcpcb.csv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]
2025-02-05 map new V2_0 LEDs
    [led_loc_addendum_V2_0_0.csv, led_locations_V1_0_5.csv, new_led_locations.csv]
2025-02-07 begin work on addendum mechanism
    [led_loc_addendum_V2_0_0.csv]
2025-02-07 create pruneCSVEntries and associated tests
    [led_loc_addendum_V2_0_0.csv, led_locations.csv, led_locations_V1_0_5.csv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]
2025-02-12 map v2 matrix 1,2 led registers
    [led_register_mappings_v2.xlsx]
2025-02-12 map matrices 3 and 4 registers
    [led_register_mappings_v2.xlsx]
2025-02-12 add v2 led mappings
    [led_register_mappings_v2.xlsx]
2025-02-13 fix versioning defines & version strings
    [main.c, routines.c, tasks.c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]
2025-02-13 add fatal error restart option & move LOGIs to LOGDs
    [app_errors.c, main.c, tasks.c]
2025-02-24 add back a few soldermask gaps
    [OO_TrafficPCB_V2_0_BOM_jlcpcb.csv, OO_TrafficPCB_V2_0_BOM_pcbway.xlsx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]
2025-02-24 create nextCSVEntryFromMark function and tests
    [data_northV1_0_5.csv]
2025-02-25 fix small led location issues
    [led_locations_V1_0_5.csv]
2025-02-25 fix byte array error & return -2 for special leds
2025-02-25 fix config_first_dir_north & bring back ESP_LOGIs
    [main.c]
2025-02-25 use V1_0_5 csv files instead of V1_0_3 dat files
    [data_north_V1_0_5.csv]
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2025-03-02 move origin to board center
    [BOM-traffic_paradise.csv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]
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2025-03-04 clean up firmware & fix bugs
    [animations.c, main.c]
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2025-03-05 add V2 error indication
    [app_errors.c]
2025-03-06 refactor to allow ease of development for multiple hardware versions
    [data_north_V1_0_5.csv]
2025-03-13 create multiple project configurations
    [partitions_V1_0.csv, partitions_V2_0.csv]
2025-03-13 fix issues with initial V2_0 build
    [V2_0_pinout.h, app_errors.c, initialize.c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]
2025-03-13 fix V2_0_0 led addendum csv
    [led_loc_addendum_V2_0_0.csv]
2025-03-13 retry I2C transactions a few times if failure
    [main.c]
2025-03-15 correct incorrect resistor values in BOM
    [OO_TrafficPCB_V2_0_BOM.csv, OO_TrafficPCB_V2_0_BOM_jlcpcb.csv, OO_TrafficPCB_V2_0_BOM_pcbway.xlsx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]
2025-03-15 fix V2_0 LED 228 red register
2025-03-15 add unit testing project to support multiple configuration
    [partitions_V1_0.csv, partitions_V2_0.csv]
2025-03-19 fix size issue with v1_0
    [initialize.c]
2025-03-19 fix documentation and off-by-one error in tests
    [animations.c]
2025-03-19 recover from wifi nvs failure
    [initialize.c]
2025-03-19 increase nvs partition size for V2_0 & maintain backward compatability
    [new_partitions_V2_0.csv]
2025-03-20 create getNextResponseBlock tests & changes for them
    [partitions_V2_0.csv]
2025-03-26 test readServerSpeedDataPreinit & fix associated bugs
    [data_north_V1_0_5.csv]
2025-03-26 v0.5.2 fix refresh timer
    [animations.c, main.c, routines.c]
2025-03-26 fix southbound curved animation bug
    [animation_config.h, animations.c]
2025-04-04 partial commit
    [new_partitions_V2_0.csv, partitions_V2_0.csv]
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2025-04-09 add mutex to led_matrix & improve component error handling
    [initialize.c]
2025-04-09 add error handling after initJobs call
    [initialize.c]
2025-04-10 fix bug removing all strobing leds
    [strobe_task.c]
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2025-04-10 fix bug where many toggle presses causes no refresh
    [main.c]
2025-04-10 fix jarring quick clear animation in V2_0
    [initialize.c, main.c, strobe_task.c]
2025-04-14 remove ErrorResources & create some component init functions
    [animations.c, app_errors.c]
2025-04-14 fix bug where quick clear would not finish
    [main.c]
2025-04-14 fix getLedMatrixStatus and component initialization order
    [initialize.c, led_matrix.c]
2025-04-14 add support_strobe option to reduce V1_0 binary size
    [partitions_V1_0_dev.csv, partitions_V1_0_prod.csv]
2025-04-14 fix bug in matrix i2c addresses
    [led_matrix.c]
2025-04-19 fix via overlapping HEAVY silksreen text
    [BOM-traffic_paradise.csv, OO_TrafficPCB_V2_0_BOM.csv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]
2025-04-19 fix BOM and reexport
    [BOM-traffic_paradise.csv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]
2025-04-19 increase LED pad size to avoid risk of tombstoning
    [BOM-traffic_paradise.csv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]
2025-04-22 move manual tests to a project configuration
    [partitions_V1_0.csv, partitions_V2_0.csv]
2025-04-23 fix inverted lat/longitude on server
    [led_loc_addendum_V2_0_0.csv, led_locations.csv, led_locations_V1_0_5.csv]
2025-04-25 remove back layer ground plane to reduce pcb reflow stress
    [BOM-traffic_paradise.csv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]
2025-05-12 fix issues on Linux
    [esp32s3-builtin.cfg]
2025-05-13 fix errors in uncommon return paths
    [app_errors.c]
2025-05-30 update nonmock tests to use http mock
    [data_north_V1_0_5.csv, data_north_add_V1_0_5.csv, data_north_add_V2_0_0.csv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]
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2025-08-27 fix UART issue when running Unity
2026-01-11 fix some LEDs
    [led_loc_addendum_V2_0_0.csv, led_locations_V1_0_5.csv]
